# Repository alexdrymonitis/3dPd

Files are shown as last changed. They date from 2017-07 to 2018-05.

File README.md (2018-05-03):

# 3dPd

This repository hosts the code, schematics, and circuit board designs made in Kicad, for a hardware digital modular synthesizer. The audio is programmed in Pure Data and the hardware control in the Arduino language.
This synthesizer is supposed to run on a Raspberry Pi 3 and a Teensy3.2. You're welcome to use any other hardware you like, but this specific hardware is supported and explained here.

## Note about the Arduino code

Go to the Arduino_code directory and read the README.txt file first. That should give you enough information about the Arduino code. Do that before you start reading the Pd patches.

## Note about the Pd patches

The heart of this project is the modular_synthesizer.pd patch. Open it and you'll see some other abstractions in there. Go into the [pd modules] sub-patch and look inside.
Each module must have its own abstraction. There are some tutorial module abstractions which show you how to build your own. Open them and read them carefully.

There's also a debug.pd patch which helps with debugging by showing input from the Teensy and printing various message concerning module connections and LED states.

### Dependencies

This project uses the following external libraries:  
zexy  
comport  
iemmatrix  
iemguts  
ggee  
list-abs  
tabreceive_mult~  

The first five libraries are being installed with "apt-get" and the last two are installed through Deken (In Pd got to Help -> Find externals and type these two names -one at a time-, the highlighted version(s) is good for your system).

Pd-0.47.0 or higher is required.

## General note

I'll upload a wiki with instructions for creating the hardware of a module and the whole system. It's in my TODO list, which will hopefully happen in the near future.
You can watch a demo video of the synthesizer here https://www.youtube.com/watch?v=HD13bDPyBWA

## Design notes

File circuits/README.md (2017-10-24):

# Circuit designs, schematics, and gerber files directory

This README file provides only very basic information about the circuits. I'm planning on releasing a wiki on how to build hardware modules in the next few days.

## Generic note about this directory

In this directory you'll find all the circuits used in this modular synthesizer. It's six circuits in total, each in its own directory. They have been designed in Kicad and all the necessary files are here. Each directory includes a README file which states which extra built-in libraries have been used. The ones I have made especially for these circuits are not mentioned in the README since their directories (library/ and .pretty/) are included here. The directories also include the gerber files for sending them to a manufacturer, plus a .png file for each side (in case of double-sided boards) in case you want to DIY etch it, and a .pdf with the schematic.

If you've never used Kicad before and want to modify any of the circuits, I recommend to read some of the tutorials provided from Kicad's website. This tutorial was very useful for me http://kicad-pcb.org/help/documentation/#_getting_started. If you just want to have them manufactured, you can send the gerber files straight to a manufacturer.

## Note about the circuits

### Parts

There's a parts list in every circuit directory with all the parts of that circuit. Where I thought it was necessary, I provide a link to the datasheet of that part. Parts are identified by their annotation from the schematic. Consult the board design (Pcbnew) to make sure which part goes where.

### Orientation of parts

The orientation of the ICs on the "module_generic_top_board" is not defined by the shape of the footprint part but by the pin numbering. If you're not sure, open Pcbnew, go to View -> 3D Viewer and there you can see the notches of the ICs which indicate their orientation.
The orientation of the IDC connectors can be defined by the pin numbering. On an actual IDC connector, you can see a small arrow at the left side of the notch. This arrow indicates that the left-most pin on the side of the notch, is pin number 1.

### Concerning manufacturing

The boards "module_generic_top_board" and "module_generic_bottom_board" are needed for every module. I would suggest to order these from a manufacturer instead of etching them your self many times. The "module_specific_board" and "module_specific_board"2 are just examples of how you can connect your parts to the generic boards (this will be analyzed in the upcoming wiki). There are two of those because I wanted to provide both orientations for the potentiometers, because of the knobs one can find (they are D-shaped knobs, so orientation is rather important). You can order few of these as well, since it is designed in such a way that can host many different layouts.

The "power_bus", "power_distributor", and "teensy_motherboard" are designed as single-side circuit boards (with the "teensy_motherboard" using three jumpers, the "power_bus" only one, and the "power_distributor" none) so that it's easier to etch them yourself. You'll need only one per board (unless you want to build more than 16 modules, then you'll need a second "power_bus", explained in the upcoming wiki), so ordering those from a manufacturer might not work out.

Eacn board has a .pdf file which you can print for DIY etching, either with toner transfer or with photo-resistant boards. The "module_generic_top_board", "module_generic_bottom_board", and "module_specific_board" have two .pdf, one for each side, while the rest three have only one .pdf file.

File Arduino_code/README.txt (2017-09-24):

Before uploading code to the Teensy you must make a small test. I had problems sending the value 13 from the Teensy to Pd. Arduino's Serial.write() function didn't work, and instead of 13 I was receiving a 10.
Searching I found that Serial.print((char)13) might do the job. On my laptop with an Arduino Uno, this does work indeed (while Serial.write(13) doesn't even work on my laptop), but on my Raspberry Pi even this didn't work, and again I was receiving a 10 in Pd.
I don't know why this is happening. I sent a mail to Pd's mailing list, but Matrin Peach, the developer of [comport] reported that he can print 13 with Serial.write() without any issues and that [comport] doesn't interpret anything. It can be because of 13 being ASCII carriage return and 10 being the line feed, which in some cases (like Arduino's Serial.println() funciton) these two ASCII values are combined. It can possibly be an Arduino compiler problem, I don't know.
I found a work around this problem by adding some extra data to the data sent from the Teensy to Pd. You should do the following test:

Upload the write.ino Arduino sketch to the Teensy and open the test13.pd patch. If you get 13 printed in Pd's console, you're good to go. Upload the modular_synthesizer.ino sketch and open the modular_synthesizer.pd patch.
If instead of 13 you get 10 printed to Pd's console, open the print13.ino sketch and the test13.pd patch. If you get 13 printed in Pd's console, you're good to go. Upload the modular_synthesizer_print.ino sketch and open the modular_synthesizer.pd patch.
If you still get 10 printed to Pd's console, upload the modular_synthesizer13.ino sketch to the Teensy. In modular_synthesizer.pd patch, change the [arduino_data] abstraction with [arduino_data13]. The rest should work as expected.

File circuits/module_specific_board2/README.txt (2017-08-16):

This board is a rather generic design for mounting potentiometers and wiring banana terminals, switches and LEDs to a module. Each module will have its own layout, so the board that hosts the parts of the module is rather specific than generic. Still, this board can host quite some different layouts the way it is designed.

The digital inputs and outputs are broken out to the right side and bottom side of the board respctively. The inputs start counting from the top and the outputs from left to right.

Four potentiometers are placed on this board which are connected to the first four multiplexer inputs. The other four are broken out on the right side of the top header, where the top pin of the four-pin header is mux pin 8, and the bottom is mux pin 5. I have included 10K pull-down resistors in case you run out of digital inputs but have some space multiplexer pins. In this case you can attach a pull-down resistor to one of these pins (or all four) and use it for a switch.

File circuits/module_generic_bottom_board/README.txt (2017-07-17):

This circuit contains the switches schematic parts library from /usr/share/kicak/library

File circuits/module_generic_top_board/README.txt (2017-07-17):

This circuit contains the Connectors_JST_PH.pretty footprint library in the project specific libraries, from ${KISYSMOD}/Connectors_JST_PH.pretty

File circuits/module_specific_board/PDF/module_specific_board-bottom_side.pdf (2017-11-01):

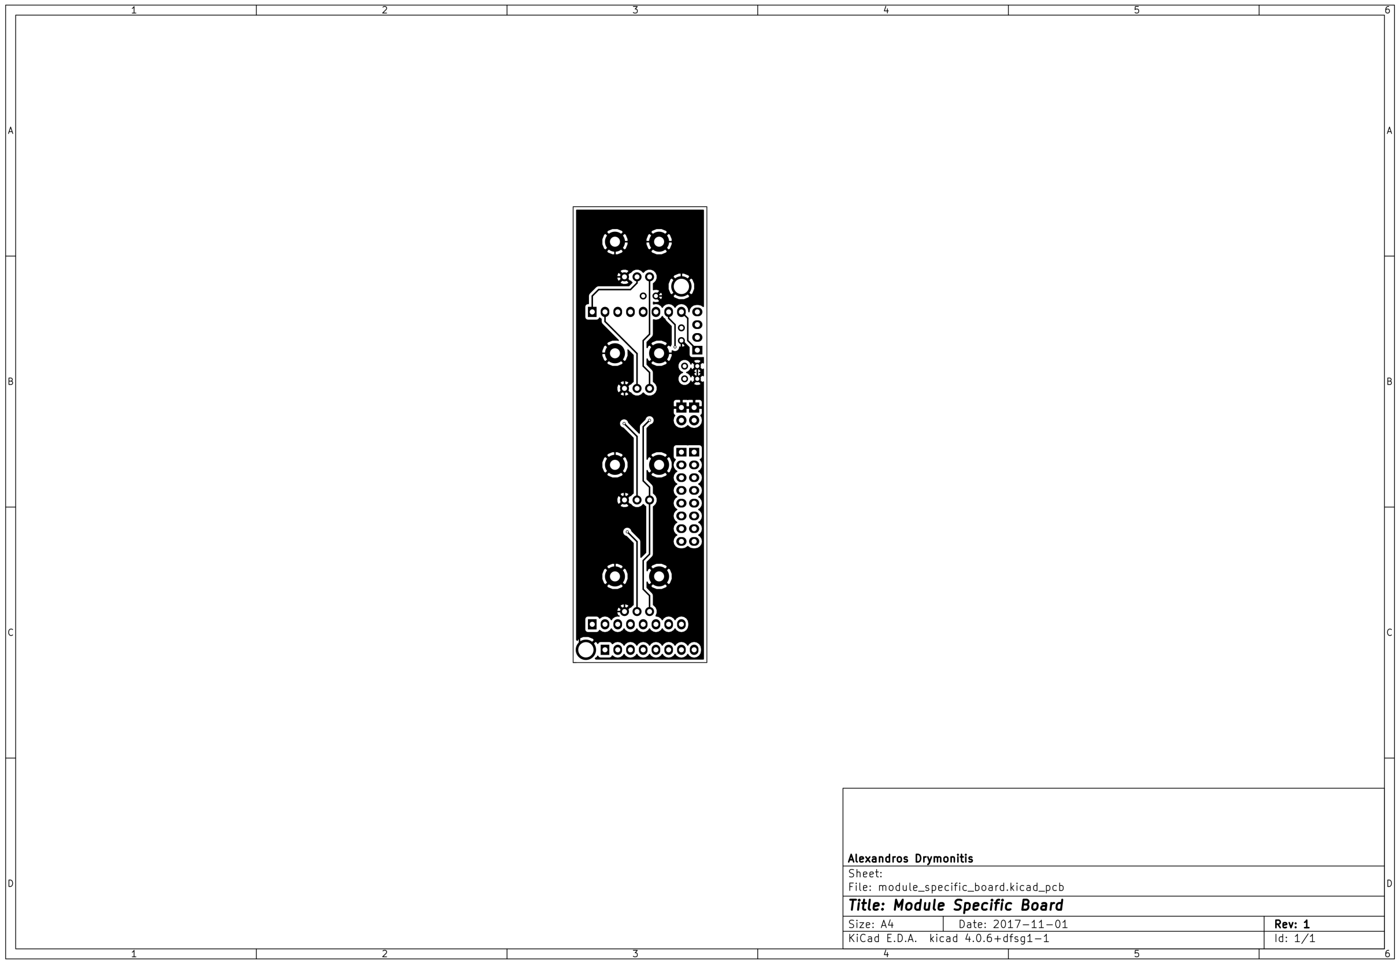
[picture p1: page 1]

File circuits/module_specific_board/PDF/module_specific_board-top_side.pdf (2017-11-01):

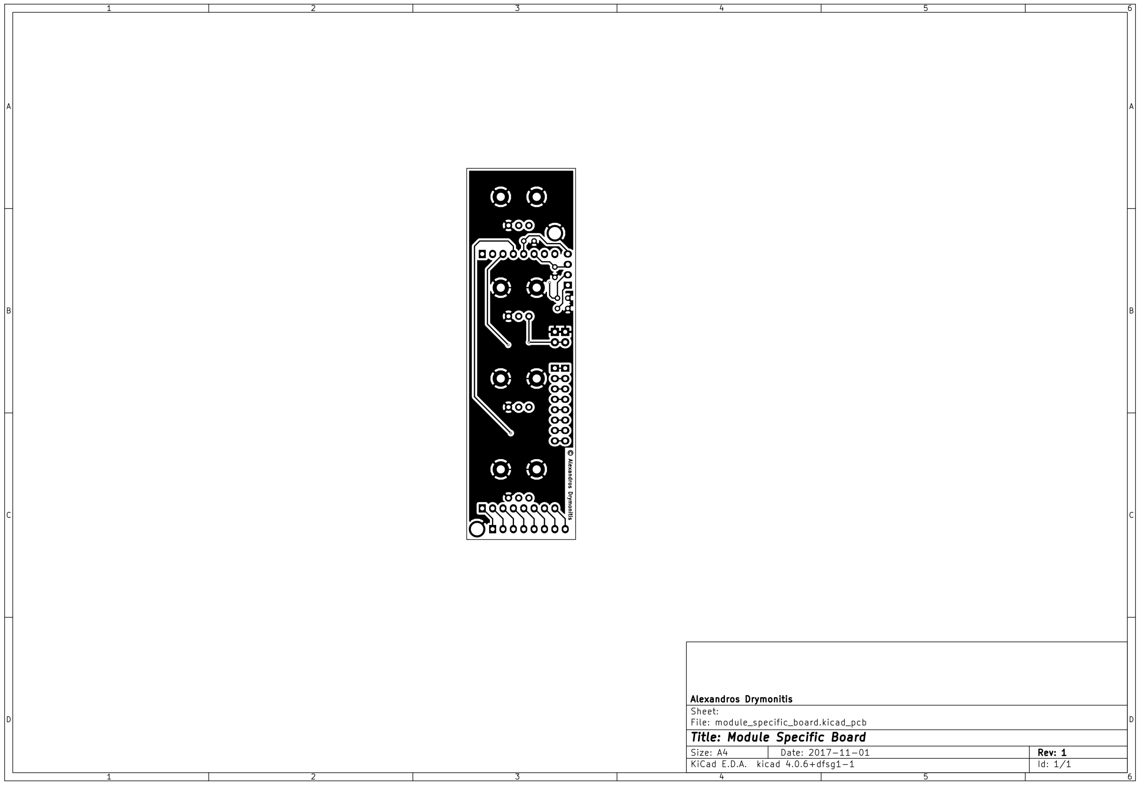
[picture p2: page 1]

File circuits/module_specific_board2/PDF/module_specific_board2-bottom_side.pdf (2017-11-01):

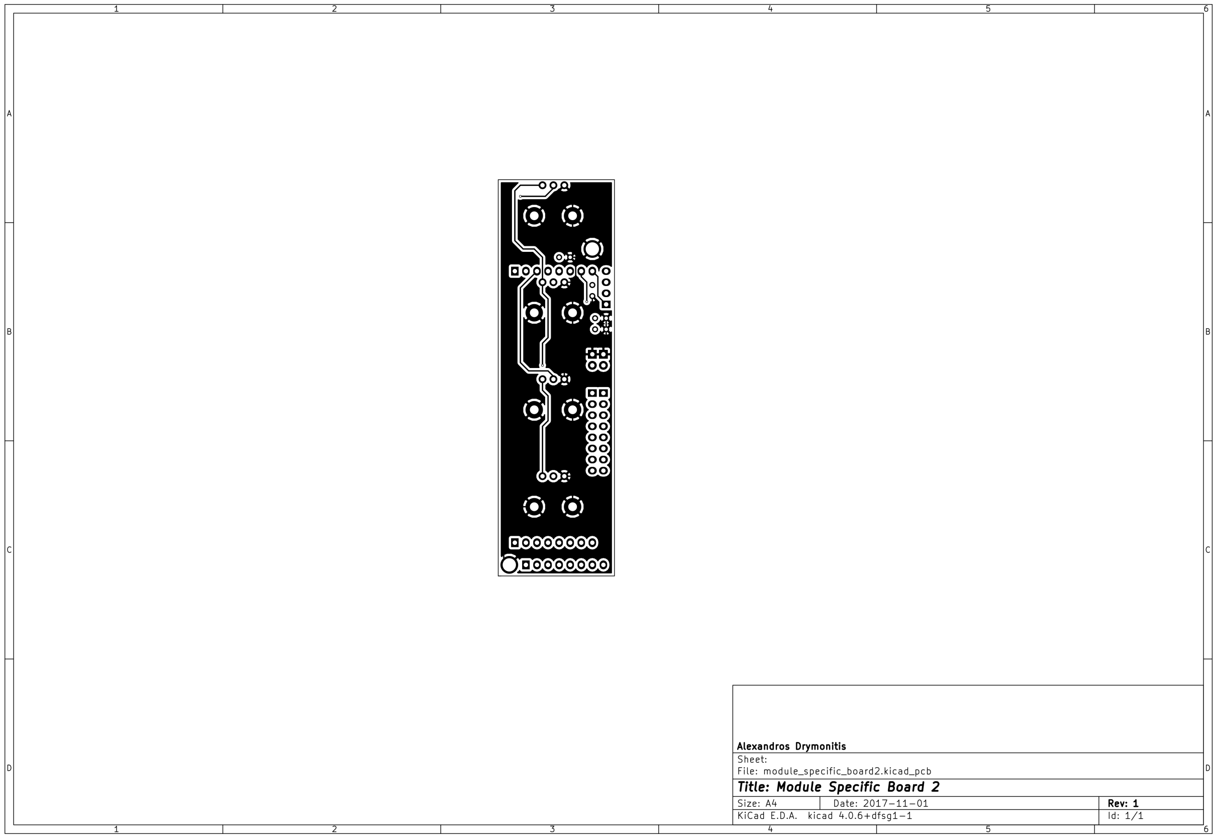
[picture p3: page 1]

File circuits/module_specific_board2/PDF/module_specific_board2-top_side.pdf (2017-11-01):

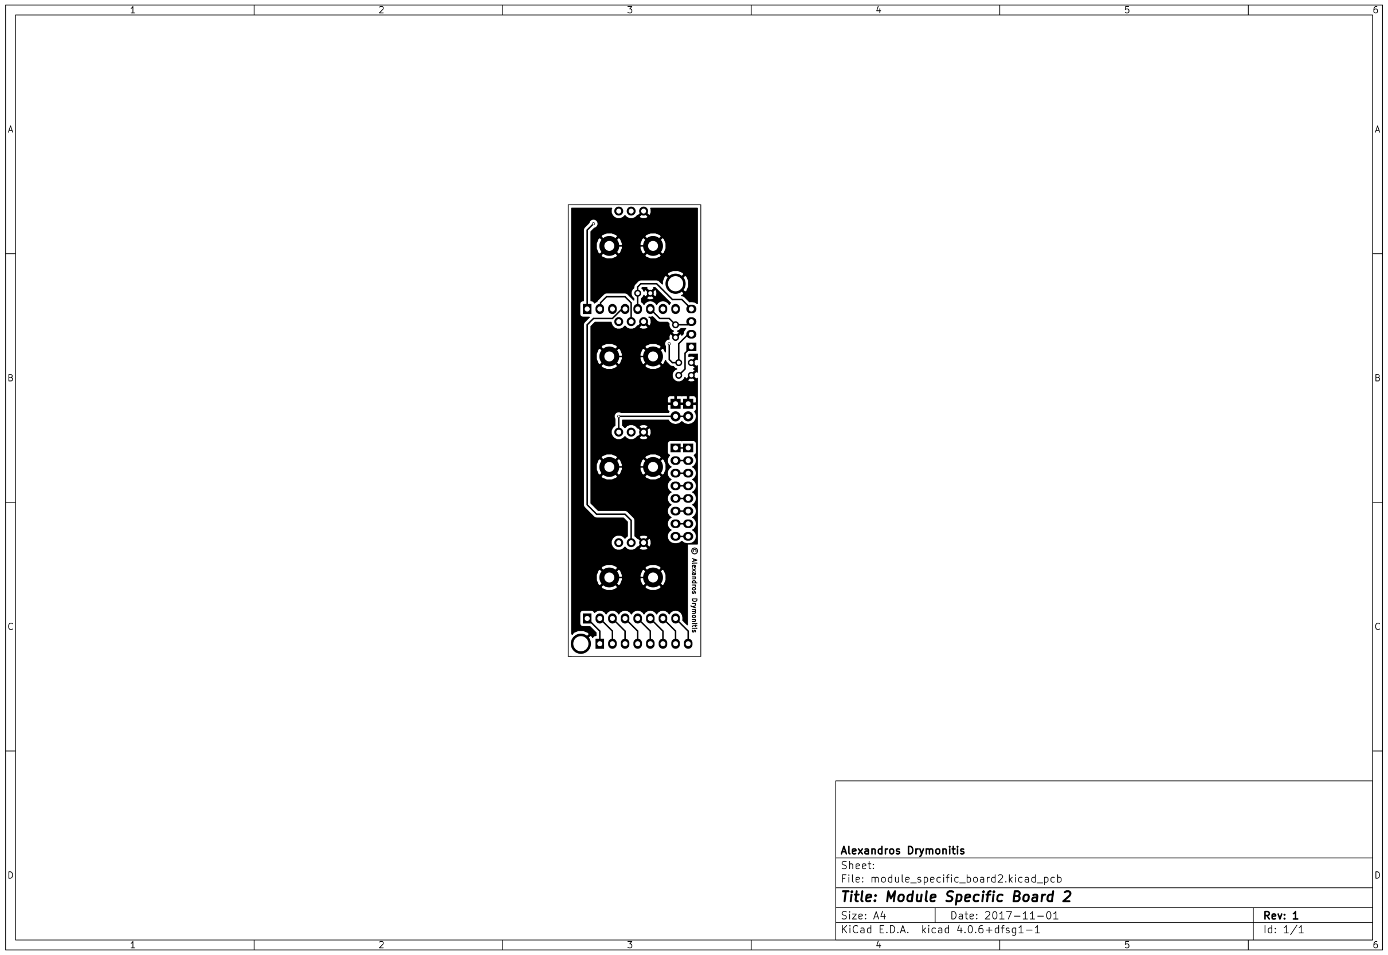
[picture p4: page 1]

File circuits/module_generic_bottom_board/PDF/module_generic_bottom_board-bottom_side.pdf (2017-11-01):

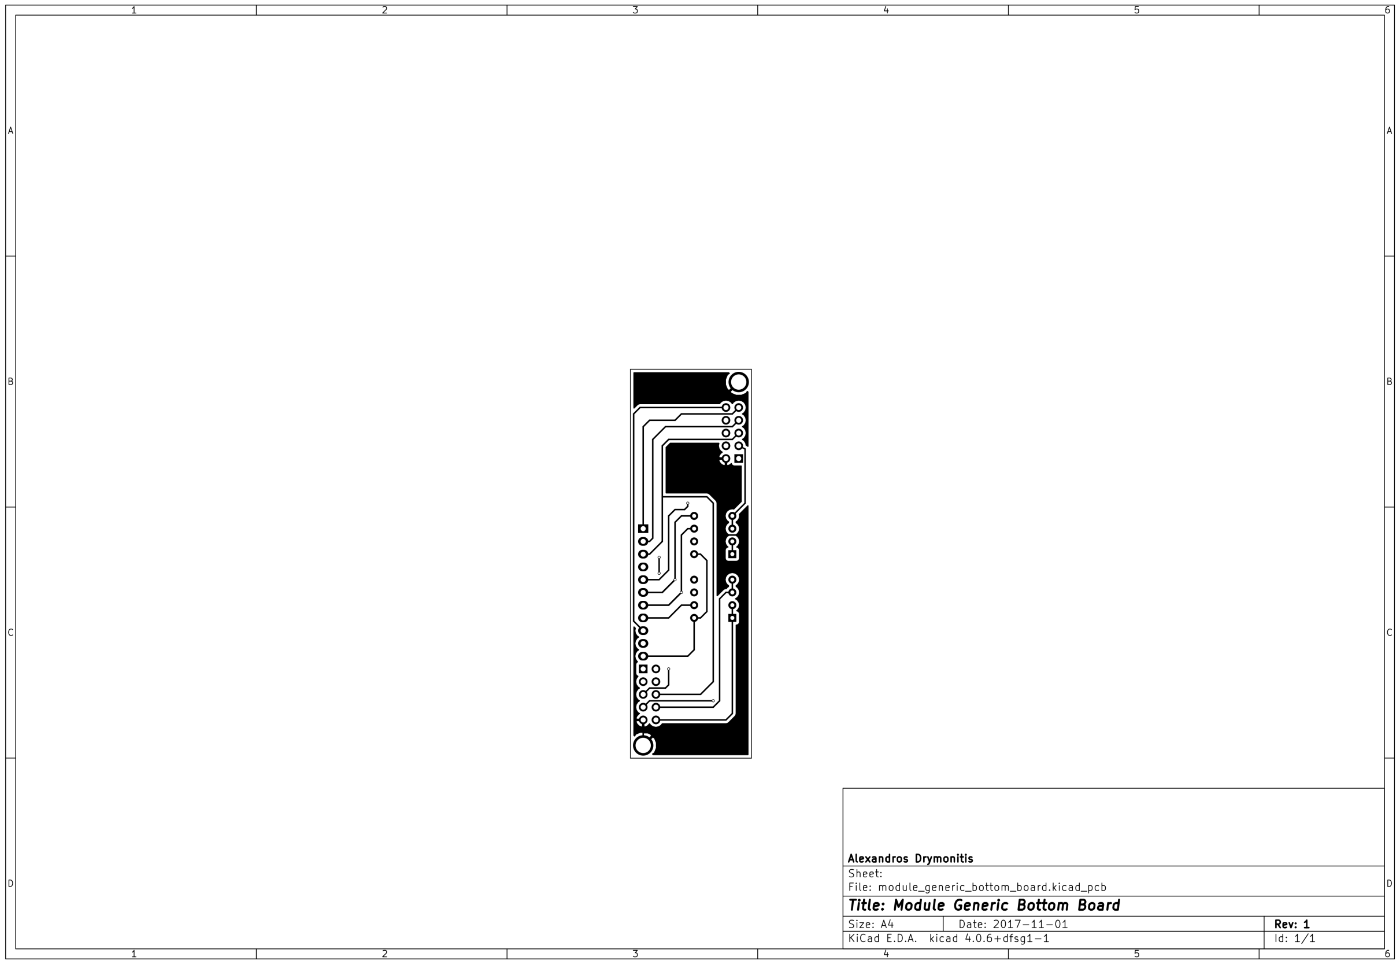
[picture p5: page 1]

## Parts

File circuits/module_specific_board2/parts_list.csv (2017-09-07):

Reference | Value | Footprint | Datasheet
P6 | CONN_01X02 | Header Male Straight 2-pin
P3 | CONN_01X08 | Header Male Straight 8-pin
P4 | CONN_01X08 | Header Male Straight 8-pin
P5 | CONN_01X08 | Header Male Straight 8-pin
J1 | Pot | ALPS Rotary Potentiometer RK09L114001T | http://www.alps.com/prod/info/E/HTML/Potentiometer/RotaryPotentiometers/RK09L/RK09L1140A66.html
J2 | Pot | ALPS Rotary Potentiometer RK09L114001T | http://www.alps.com/prod/info/E/HTML/Potentiometer/RotaryPotentiometers/RK09L/RK09L1140A66.html
J3 | Pot | ALPS Rotary Potentiometer RK09L114001T | http://www.alps.com/prod/info/E/HTML/Potentiometer/RotaryPotentiometers/RK09L/RK09L1140A66.html
J4 | Pot | ALPS Rotary Potentiometer RK09L114001T | http://www.alps.com/prod/info/E/HTML/Potentiometer/RotaryPotentiometers/RK09L/RK09L1140A66.html
R1 | 10K resistor, 1/4W | Discret:R1
R2 | 10K resistor, 1/4W | Discret:R1
R3 | 10K resistor, 1/4W | Discret:R1
R4 | 10K resistor, 1/4W | Discret:R1

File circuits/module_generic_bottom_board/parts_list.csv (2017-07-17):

Reference | Value | Type
P2 | CONN_02X05 | IDC Connector 2x5 Angled
P1 | CONN_02X05 | IDC Connector 2x5 Angled
P3 | CONN_01X11 | Header Male 11-pin Straight
S1 | SW_DIP_x4 | DIP Switch 4-position Piano Type
S2 | SW_DIP_x4 | DIP Switch 4-position Piano Type

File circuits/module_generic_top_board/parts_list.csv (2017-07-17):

Reference | Value | Type | Datasheet
C1 | 0.1uF | Capacitor Ceramic Unpolarized
C2 | 0.1uF | Capacitor Ceramic Unpolarized
C3 | 0.1uF | Capacitor Ceramic Unpolarized
RR1 | 10K | Resistor Network 8 + 1
P2 | CONN_01X08 | Female Header Straight 8-pin 0.1 Inch
P1 | CONN_01X08 | Female Header Straight 8-pin 0.1 Inch
P4 | CONN_01X08 | Female Header Straight 8-pin 0.1 Inch
P5 | CONN_01X02 | Female Header Straight 2-pin 0.1 Inch
P6 | CONN_01X11 | Female Header Straight 11-pin 0.1 Inch
P3 | CONN_01X03 | JST PH Connector Male Angled 3-pin
U3 | 74HC165 | 8-bit Input Shift Register | https://cdn.sparkfun.com/datasheets/BreakoutBoards/sn54hc165.pdf
U2 | 74HC595 | 8-bit Output Shift Register | http://www.ti.com/lit/ds/symlink/sn74hc595.pdf
U1 | 4051 | 8-channel Analog Multiplexer | http://grobotronics.com/images/datasheets/schs354a.pdf
R1 | 10K | Resistor

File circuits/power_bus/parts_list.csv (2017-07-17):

Reference | Value | Type | Datasheet
U1 | CD4067 | 16-channel Analog Multiplexer 4067 | https://www.sparkfun.com/datasheets/IC/CD74HC4067.pdf
P2 | CONN_01X03 | JST PH Connector Male Angled 3-pin
P10 | CONN_01X03 | JST PH Connector Male Angled 3-pin
P14 | CONN_01X03 | JST PH Connector Male Angled 3-pin
P19 | CONN_01X03 | JST PH Connector Male Angled 3-pin
P3 | CONN_01X03 | JST PH Connector Male Angled 3-pin
P11 | CONN_01X03 | JST PH Connector Male Angled 3-pin
P15 | CONN_01X03 | JST PH Connector Male Angled 3-pin
P20 | CONN_01X03 | JST PH Connector Male Angled 3-pin
P4 | CONN_01X03 | JST PH Connector Male Angled 3-pin
P12 | CONN_01X03 | JST PH Connector Male Angled 3-pin
P16 | CONN_01X03 | JST PH Connector Male Angled 3-pin
P21 | CONN_01X03 | JST PH Connector Male Angled 3-pin
P5 | CONN_01X03 | JST PH Connector Male Angled 3-pin
P13 | CONN_01X03 | JST PH Connector Male Angled 3-pin
P17 | CONN_01X03 | JST PH Connector Male Angled 3-pin
P22 | CONN_01X03 | JST PH Connector Male Angled 3-pin
P1 | CONN_02X03 | IDC Connector Male 2x3 Straight
C2 | 0.1uF | Capacitor Ceramic Unpolarized
P18 | CONN_01X02 | Screw Terminal 2-pin 5mm Pitch
R1 | 10K | Resistor

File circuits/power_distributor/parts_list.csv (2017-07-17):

Reference | Value | Footprint | Datasheet
P1 | CONN_01X02 | Screw Temrinal 2-pin 5mm Pitch
P2 | CONN_01X02 | Screw Temrinal 2-pin 5mm Pitch
P3 | CONN_01X02 | Screw Temrinal 2-pin 5mm Pitch
P4 | CONN_01X02 | Screw Temrinal 2-pin 5mm Pitch
P5 | CONN_01X02 | Screw Temrinal 2-pin 5mm Pitch
U1 | LD1117S33TR | Voltage Regulator LD1117 - 3.3V 800mA | http://grobotronics.com/images/datasheets/ld1117.pdf
C1 | 100nF | Capacitor Ceramic Unpolarized
C2 | 10uF | Capacitor Electrolytic Polarized

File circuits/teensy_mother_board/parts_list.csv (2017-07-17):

Reference | Value | Footprint
P9 | CONN_01X14 | Header Male 14-pin Straight (to host Teensy)
P8 | CONN_01X14 | Header Male 14-pin Straight (to host Teensy)
P5 | CONN_02X05 | IDC Connector Male 2x5 Straight
P6 | CONN_02X03 | IDC Connector Male 2x3 Straight
P7 | CONN_02X03 | IDC Connector Male 2x3 Straight
P10 | CONN_01X02 | Screw Terminal 2-pin 5mm Pitch
P11 | CONN_01X02 | JST PH Connector Male Angled 2-pin
P13 | CONN_01X02 | JST PH Connector Male Angled 2-pin
P12 | CONN_01X02 | JST PH Connector Male Angled 2-pin

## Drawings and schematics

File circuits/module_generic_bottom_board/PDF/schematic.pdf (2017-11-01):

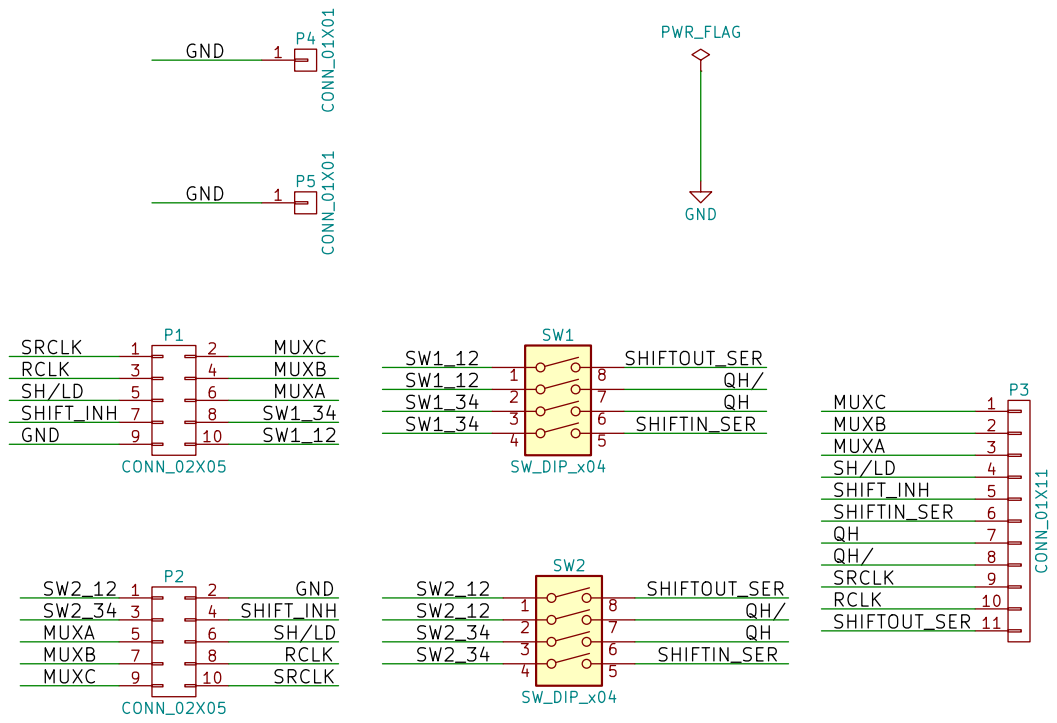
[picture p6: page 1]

File: module_generic_bottom_board.sch Sheet: / Alexandros Drymonitis

Id: 1/1 Title: ModuleGeneric Bottom Board

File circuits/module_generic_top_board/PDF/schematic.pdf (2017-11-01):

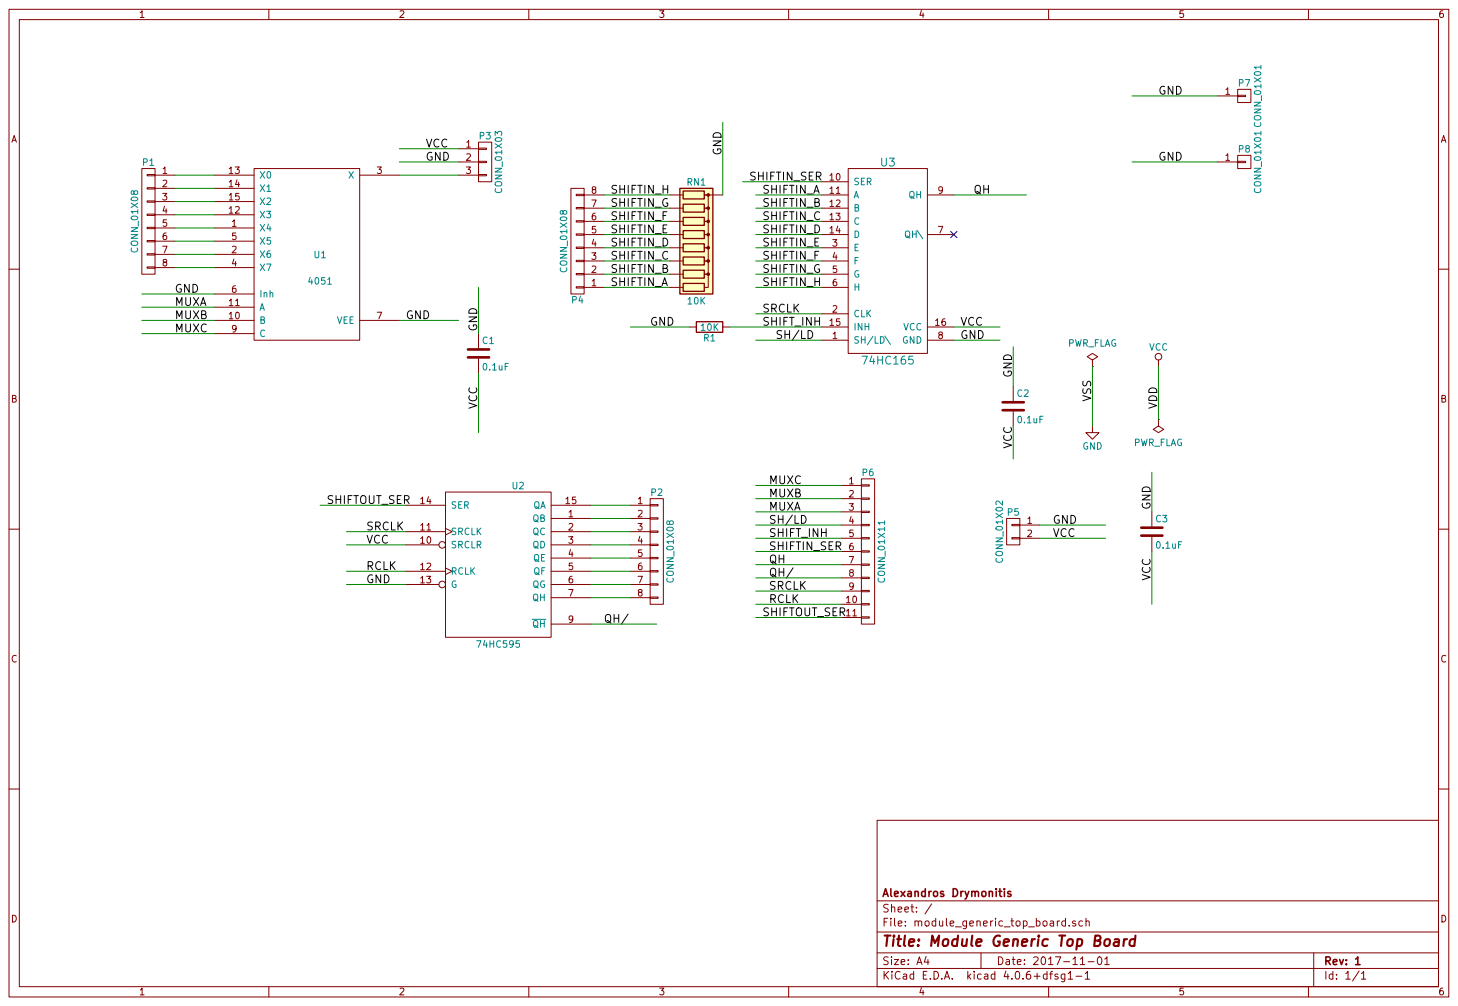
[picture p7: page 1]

GND MUXA MUXB MUXC

File: module_generic_top_board.sch Sheet: / Alexandros Drymonitis

Id: 1/1 Title: Module Generic Top Board

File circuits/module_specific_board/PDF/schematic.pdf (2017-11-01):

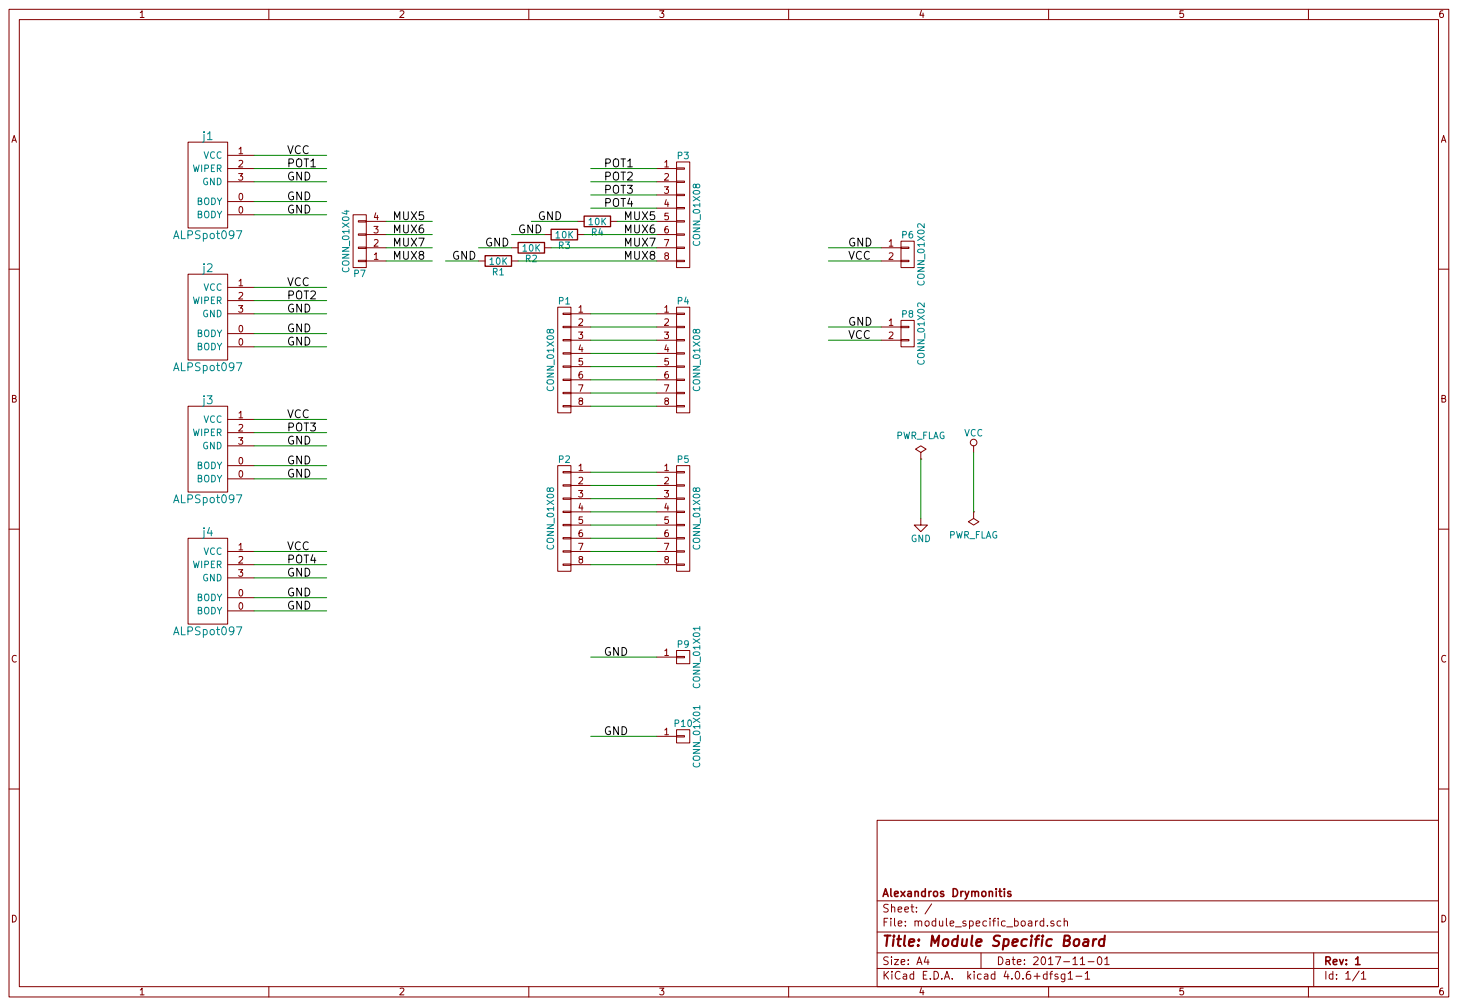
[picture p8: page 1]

Id: 1/1 Title: Module Specific Board

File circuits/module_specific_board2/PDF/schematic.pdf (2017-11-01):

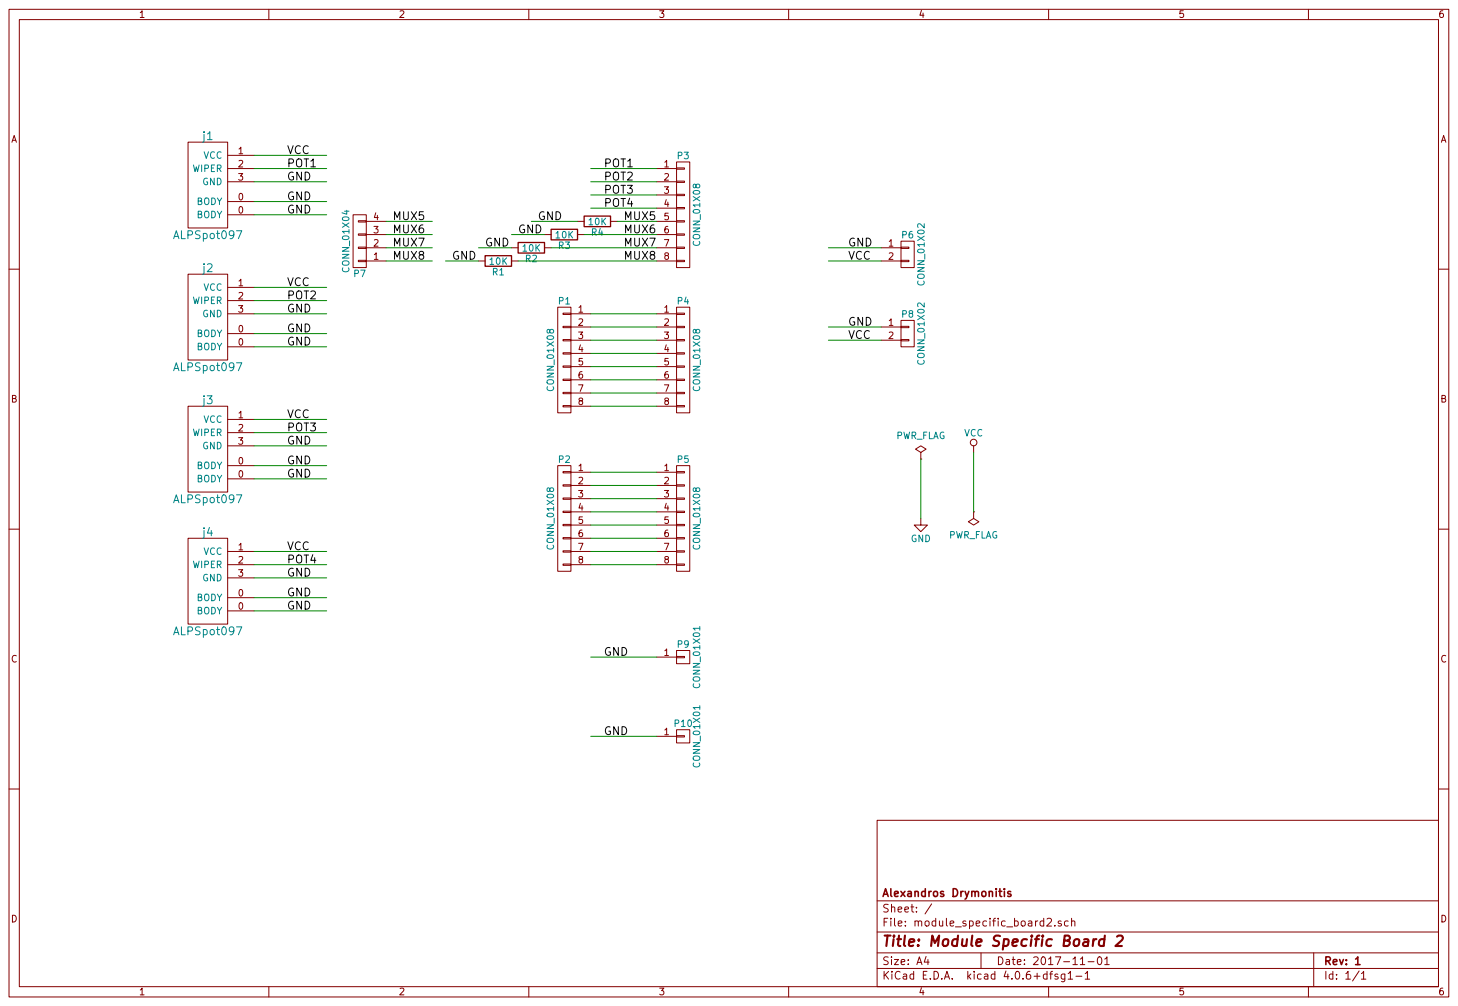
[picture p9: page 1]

Id: 1/1 Title: Module Specific Board 2

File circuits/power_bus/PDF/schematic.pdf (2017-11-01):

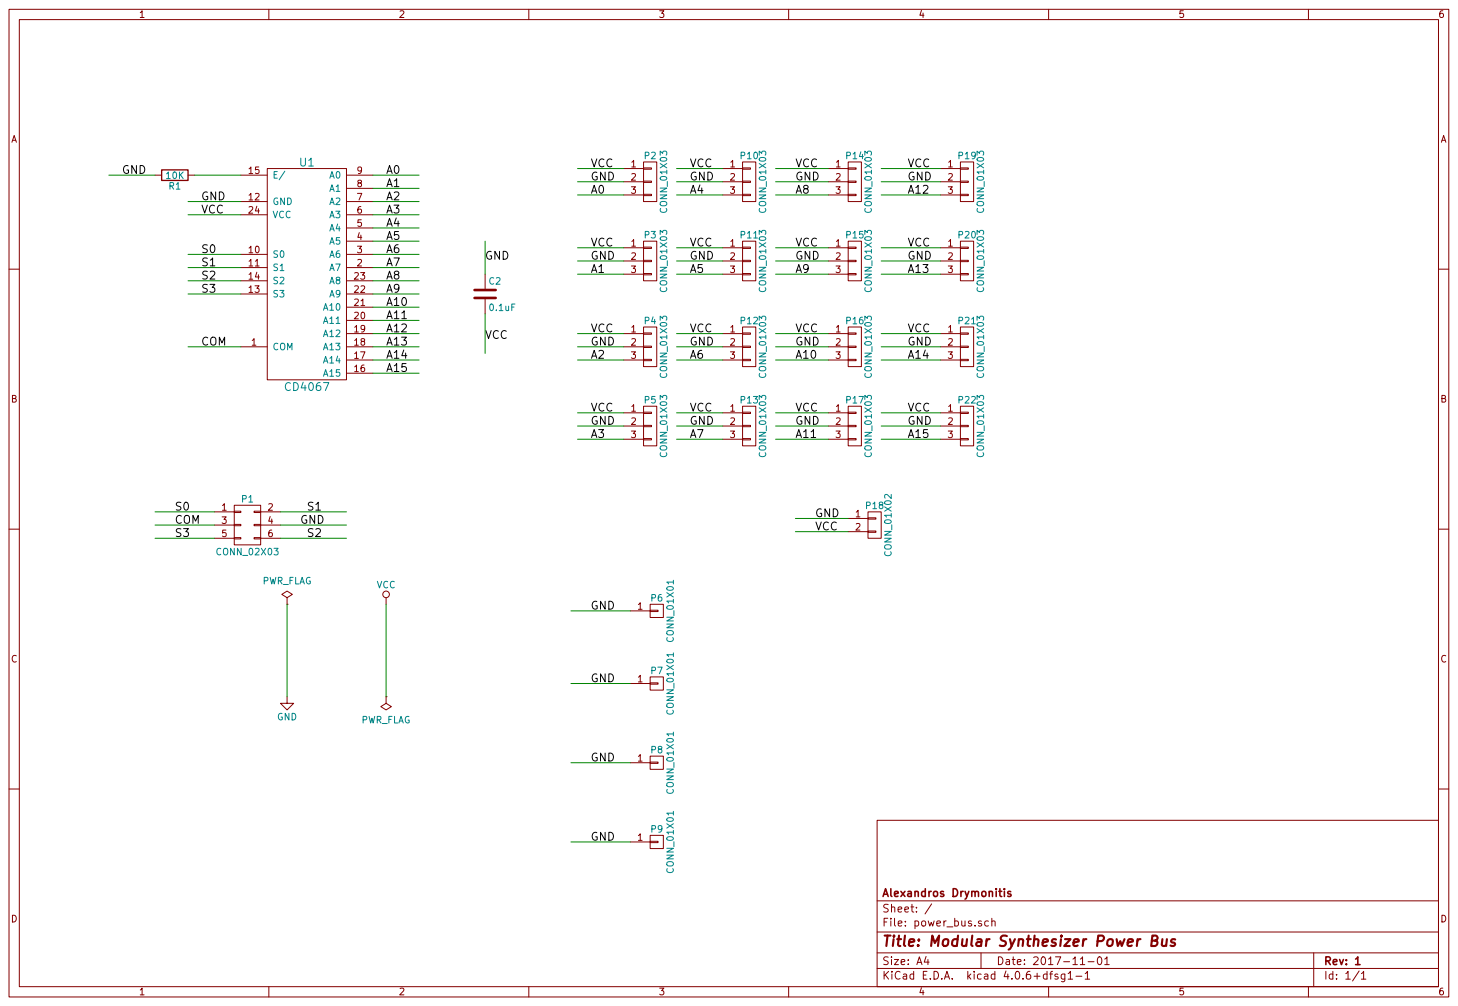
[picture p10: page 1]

File: power_bus.sch Sheet: / Alexandros Drymonitis

Id: 1/1 Title: Modular Synthesizer Power Bus

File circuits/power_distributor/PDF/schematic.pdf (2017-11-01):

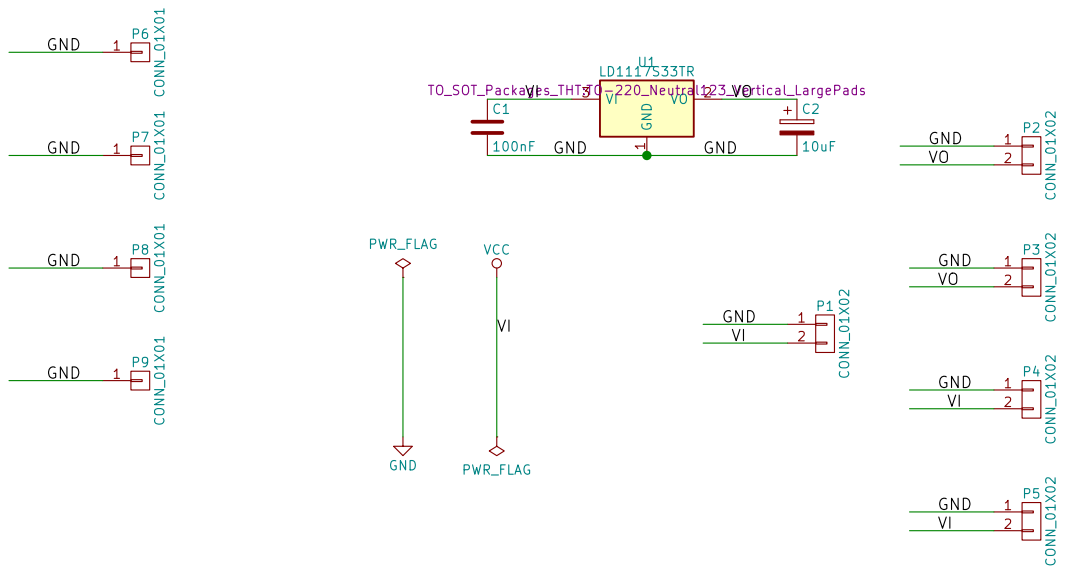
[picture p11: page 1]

File: power_distributor.sch Sheet: / Alexandros Drymonitis

Id: 1/1 Title: Modular Synthesizer Power Distributor

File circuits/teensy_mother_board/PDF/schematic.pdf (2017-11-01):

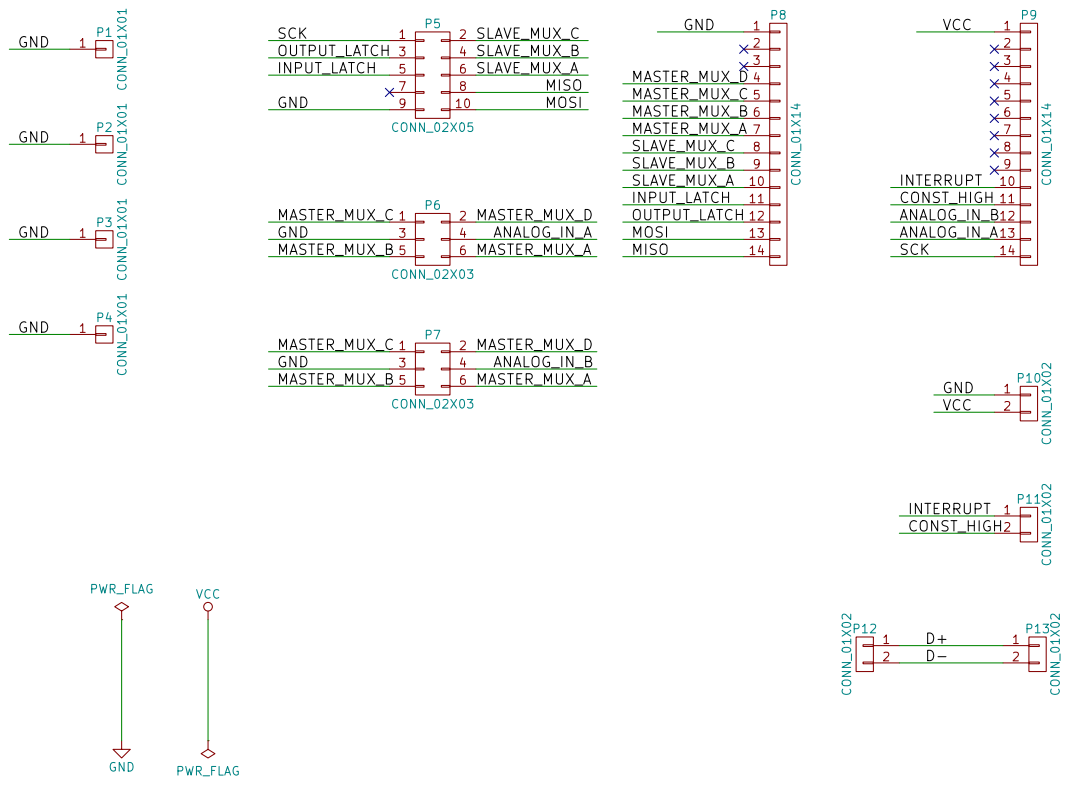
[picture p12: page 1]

File: teensy_mother_board.sch Sheet: / Alexandros Drymonitis

Id: 1/1 Title: Teensy Mother Board

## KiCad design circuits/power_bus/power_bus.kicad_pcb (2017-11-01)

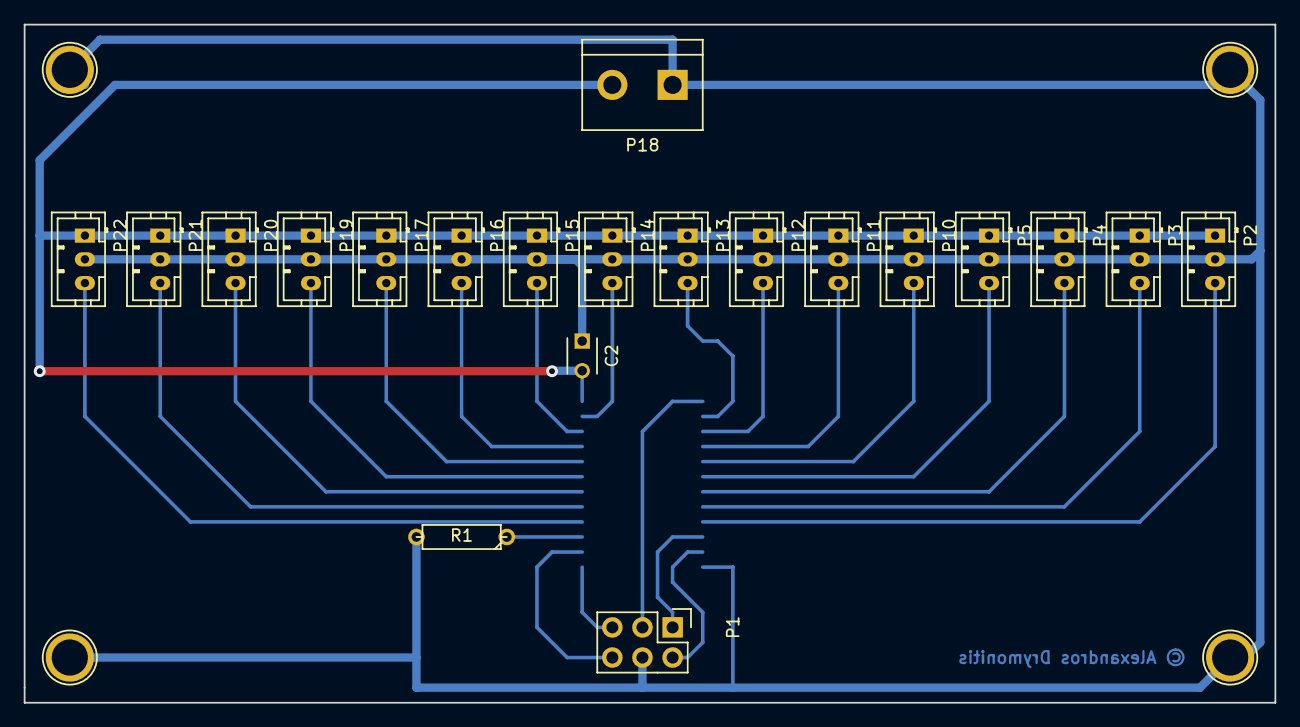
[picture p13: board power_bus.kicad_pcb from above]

Board: 2 copper layers, 105.4 x 57.2 mm, 25 parts (1 on the bottom side), 24 nets.

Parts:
C2: 0.1uF; C_Disc_D3_P2.5
P1: CONN_02X03; Pin_Header_Straight_2x03
P2, P3, P4, P5, P10, P11, P12, P13, P14, P15, P16, P17, P19, P20, P21, P22: CONN_01X03; Connectors_JST_B3B-PH-K
P6, P7, P8, P9: CONN_01X01; hole
P18: CONN_01X02; bornier2
R1: 10K; R3
U1: CD4067

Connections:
/A0: P2.3, U1.9
/A1: P3.3, U1.8
/A2: P4.3, U1.7
/A3: P5.3, U1.6
/A4: P10.3, U1.5
/A5: P11.3, U1.4
/A6: P12.3, U1.3
/A7: P13.3, U1.2
/A8: P14.3, U1.23
/A9: P15.3, U1.22
/A10: P16.3, U1.21
/A11: P17.3, U1.20
/A12: P19.3, U1.19
/A13: P20.3, U1.18
/A14: P21.3, U1.17
/A15: P22.3, U1.16
/COM: P1.3, U1.1
/S0: P1.1, U1.10
/S1: P1.2, U1.11
/S2: P1.6, U1.14
/S3: P1.5, U1.13
GND: C2.1, P1.4, P2.2, P3.2, P4.2, P5.2, P6.1, P7.1, P8.1, P9.1, P10.2, P11.2, P12.2, P13.2, P14.2, P15.2, P16.2, P17.2, P18.1, P19.2, P20.2, P21.2, P22.2, R1.2, U1.12
unnamed: R1.1, U1.15
VCC: C2.2, P2.1, P3.1, P4.1, P5.1, P10.1, P11.1, P12.1, P13.1, P14.1, P15.1, P16.1, P17.1, P18.2, P19.1, P20.1, P21.1, P22.1, U1.24

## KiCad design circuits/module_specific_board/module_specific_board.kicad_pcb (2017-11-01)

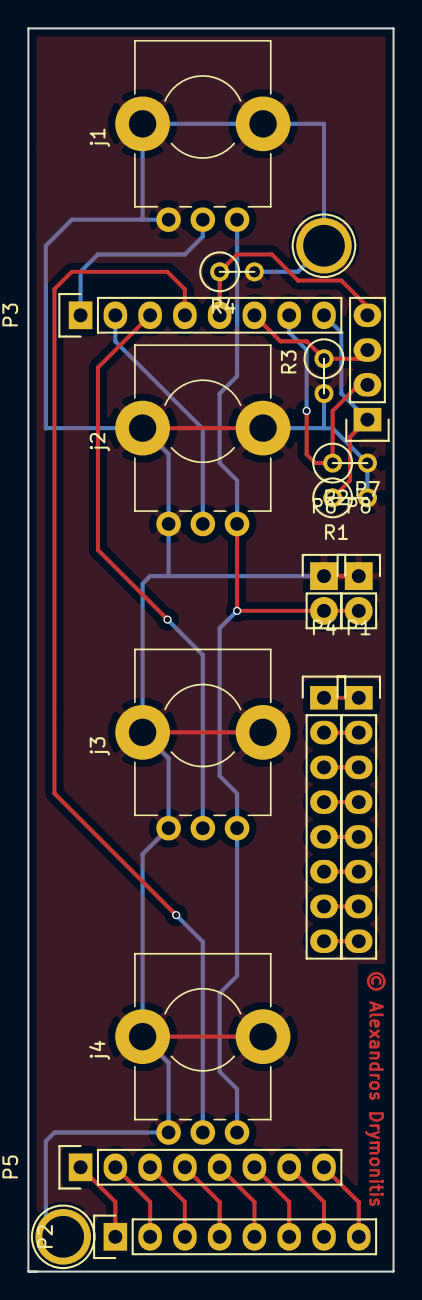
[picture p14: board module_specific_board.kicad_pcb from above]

Board: 2 copper layers, 26.7 x 90.8 mm, 18 parts (0 on the bottom side), 26 nets.

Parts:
P1, P2, P3, P4, P5: CONN_01X08; Pin_Header_Straight_1x08
P6, P8: CONN_01X02; Pin_Header_Straight_1x02
P7: CONN_01X04; Pin_Header_Straight_1x04
P9, P10: CONN_01X01; hole
R1, R2, R3, R4: 10K; R1
j1, j2, j3, j4: ALPSpot097; Potentiometer_Alps_RK09K_Horizontal

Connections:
/MUX5: P3.5, P7.4, R4.1
/MUX6: P3.6, P7.3, R3.1
/MUX7: P3.7, P7.2, R2.1
/MUX8: P3.8, P7.1, R1.1
/POT1: P3.1, j1.2
/POT2: P3.2, j2.2
/POT3: P3.3, j3.2
/POT4: P3.4, j4.2
GND: P6.1, P8.1, P9.1, P10.1, R1.2, R2.2, R3.2, R4.2, j1.0, j1.3, j2.0, j2.3, j3.0, j3.3, j4.0, j4.3
unnamed: P1.1, P4.1
unnamed: P1.2, P4.2
unnamed: P1.3, P4.3
unnamed: P1.4, P4.4
unnamed: P1.5, P4.5
unnamed: P1.6, P4.6
unnamed: P1.7, P4.7
unnamed: P1.8, P4.8
unnamed: P2.1, P5.1
unnamed: P2.2, P5.2
unnamed: P2.3, P5.3
unnamed: P2.4, P5.4
unnamed: P2.5, P5.5
unnamed: P2.6, P5.6
unnamed: P2.7, P5.7
unnamed: P2.8, P5.8
VCC: P6.2, P8.2, j1.1, j2.1, j3.1, j4.1

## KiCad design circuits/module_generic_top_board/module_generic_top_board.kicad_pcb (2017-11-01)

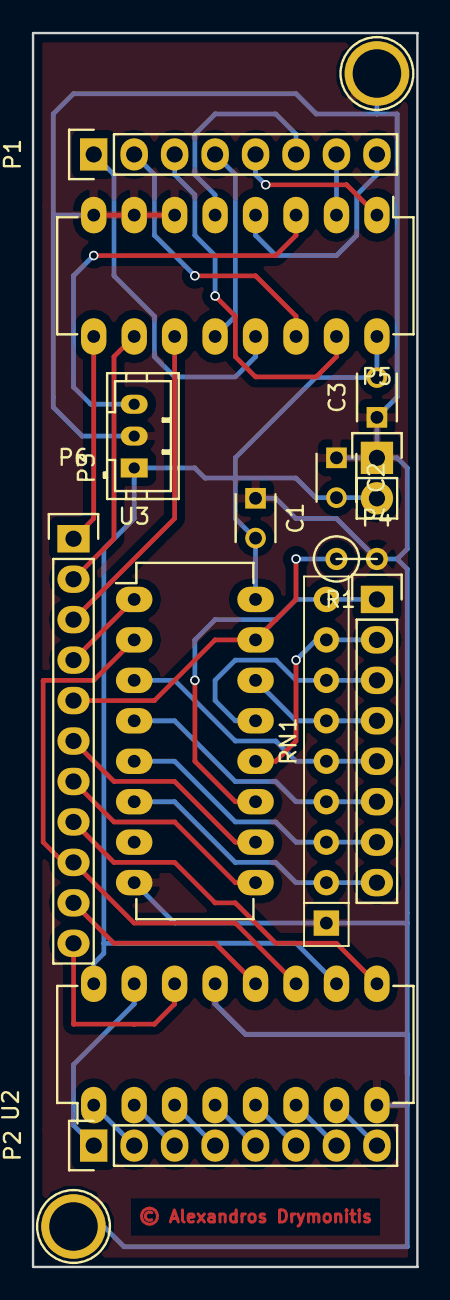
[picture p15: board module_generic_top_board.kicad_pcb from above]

Board: 2 copper layers, 24.1 x 77.5 mm, 16 parts (0 on the bottom side), 38 nets.

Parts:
C1, C2, C3: 0.1uF; C_Disc_D3_P2.5
P1, P2, P4: CONN_01X08; Pin_Header_Straight_1x08
P3: CONN_01X03; Connectors_JST_B3B-PH-K
P5: CONN_01X02; Pin_Header_Straight_1x02
P6: CONN_01X11; Pin_Header_Straight_1x11
P7, P8: CONN_01X01; hole
R1: 10K; R1
RN1: 10K; R_Array_SIP9
U1: 4051; DIP-16_W7.62mm_LongPads
U2: 74HC595; DIP-16_W7.62mm_LongPads
U3: 74HC165; DIP-16_W7.62mm_LongPads

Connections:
/MUXA: P6.3, U1.11
/MUXB: P6.2, U1.10
/MUXC: P6.1, U1.9
/QH: P6.7, U3.9
/QH/: P6.8, U2.9
/RCLK: P6.10, U2.12
/SH/LD: P6.4, U3.1
/SHIFTIN_A: P4.1, RN1.9, U3.11
/SHIFTIN_B: P4.2, RN1.8, U3.12
/SHIFTIN_C: P4.3, RN1.7, U3.13
/SHIFTIN_D: P4.4, RN1.6, U3.14
/SHIFTIN_E: P4.5, RN1.5, U3.3
/SHIFTIN_F: P4.6, RN1.4, U3.4
/SHIFTIN_G: P4.7, RN1.3, U3.5
/SHIFTIN_H: P4.8, RN1.2, U3.6
/SHIFTIN_SER: P6.6, U3.10
/SHIFTOUT_SER: P6.11, U2.14
/SHIFT_INH: P6.5, R1.1, U3.15
/SRCLK: P6.9, U2.11, U3.2
GND: C1.1, C2.1, C3.1, P3.2, P5.1, P7.1, P8.1, R1.2, RN1.1, U1.6, U1.7, U1.8, U2.8, U2.13, U3.8
unnamed: P1.1, U1.13
unnamed: P1.2, U1.14
unnamed: P1.3, U1.15
unnamed: P1.4, U1.12
unnamed: P1.5, U1.1
unnamed: P1.6, U1.5
unnamed: P1.7, U1.2
unnamed: P1.8, U1.4
unnamed: P2.1, U2.15
unnamed: P2.2, U2.1
unnamed: P2.3, U2.2
unnamed: P2.4, U2.3
unnamed: P2.5, U2.4
unnamed: P2.6, U2.5
unnamed: P2.7, U2.6
unnamed: P2.8, U2.7
unnamed: P3.3, U1.3
VCC: C1.2, C2.2, C3.2, P3.1, P5.2, U1.16, U2.10, U2.16, U3.16

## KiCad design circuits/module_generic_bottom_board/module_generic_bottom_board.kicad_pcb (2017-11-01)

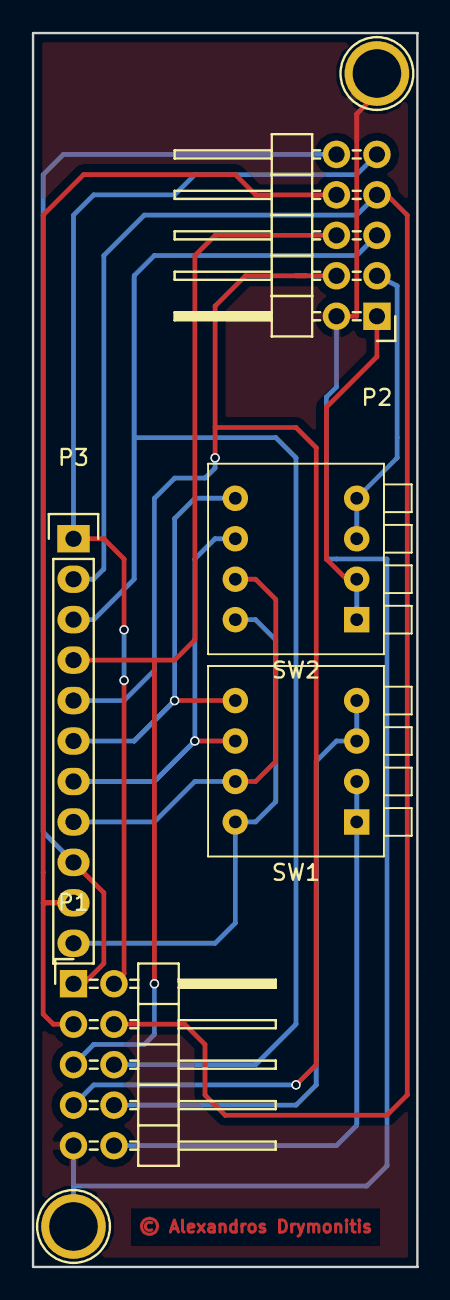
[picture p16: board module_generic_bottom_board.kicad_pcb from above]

Board: 2 copper layers, 24.1 x 77.5 mm, 7 parts (0 on the bottom side), 16 nets.

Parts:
P1, P2: CONN_02X05; Pin_Header_Angled_2x05
P3: CONN_01X11; Pin_Header_Straight_1x11
P4, P5: CONN_01X01; hole
SW1, SW2: SW_DIP_x04; SW_DIP_x4_W7.62mm_Piano

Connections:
/MUXA: P1.6, P2.5, P3.3
/MUXB: P1.4, P2.7, P3.2
/MUXC: P1.2, P2.9, P3.1
/QH: P3.7, SW1.6, SW2.6
/QH/: P3.8, SW1.7, SW2.7
/RCLK: P1.3, P2.8, P3.10
/SH/LD: P1.5, P2.6, P3.4
/SHIFTIN_SER: P3.6, SW1.5, SW2.5
/SHIFTOUT_SER: P3.11, SW1.8, SW2.8
/SHIFT_INH: P1.7, P2.4, P3.5
/SRCLK: P1.1, P2.10, P3.9
/SW1_12: P1.10, SW1.1, SW1.2
/SW1_34: P1.8, SW1.3, SW1.4
/SW2_12: P2.1, SW2.1, SW2.2
/SW2_34: P2.3, SW2.3, SW2.4
GND: P1.9, P2.2, P4.1, P5.1

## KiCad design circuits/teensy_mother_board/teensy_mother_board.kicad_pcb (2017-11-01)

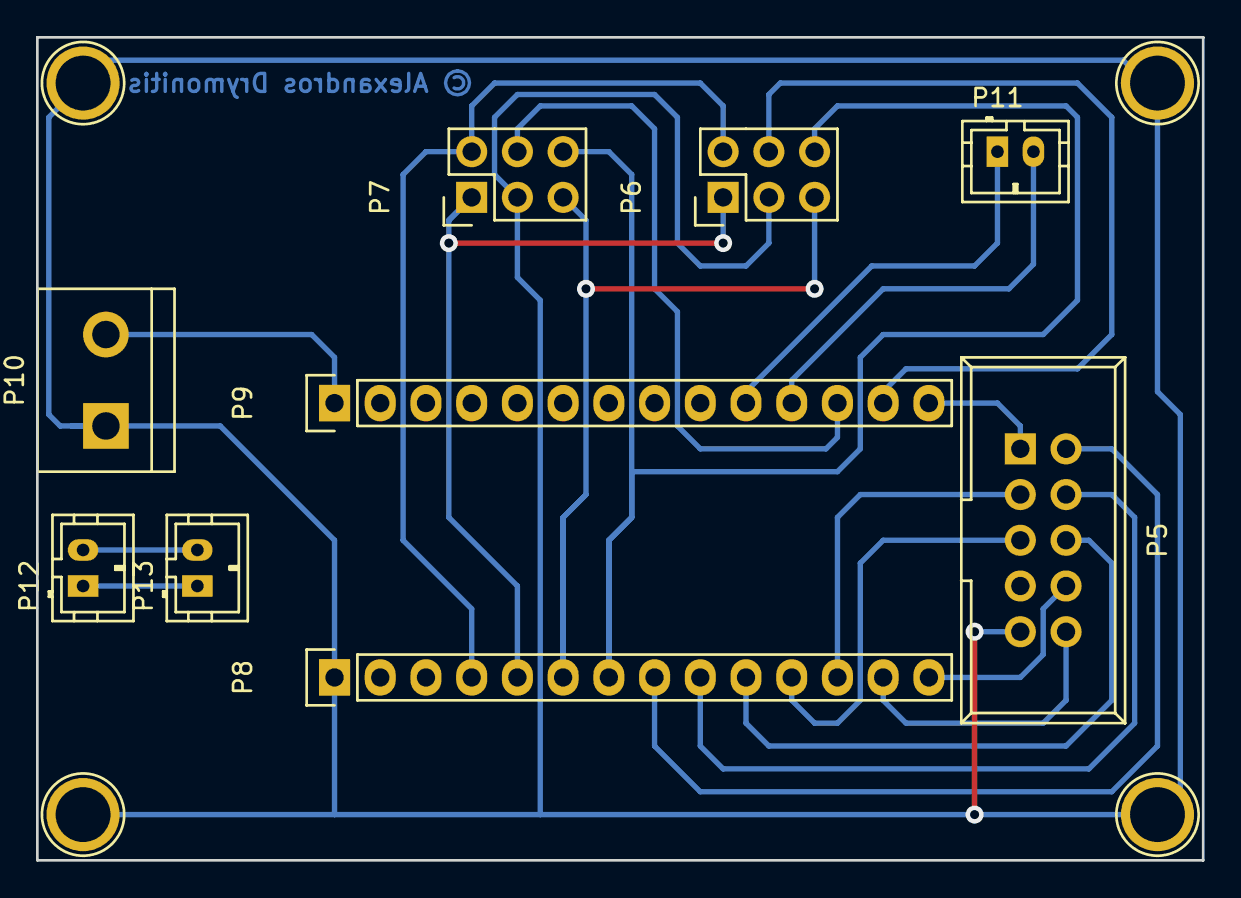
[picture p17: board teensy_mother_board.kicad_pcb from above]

Board: 2 copper layers, 64.8 x 45.7 mm, 13 parts (0 on the bottom side), 20 nets.

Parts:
P1, P2, P3, P4: CONN_01X01; hole
P5: CONN_02X05; IDC_Header_Straight_10pins
P6, P7: CONN_02X03; Pin_Header_Straight_2x03
P8, P9: CONN_01X14; Pin_Header_Straight_1x14
P10: CONN_01X02; bornier2
P11, P12, P13: CONN_01X02; Connectors_JST_B2B-PH-K

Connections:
/ANALOG_IN_A: P6.4, P9.13
/ANALOG_IN_B: P7.4, P9.12
/CONST_HIGH: P9.11, P11.2
/D+: P12.1, P13.1
/D-: P12.2, P13.2
/INPUT_LATCH: P5.5, P8.11
/INTERRUPT: P9.10, P11.1
/MASTER_MUX_A: P6.6, P7.6, P8.7
/MASTER_MUX_B: P6.5, P7.5, P8.6
/MASTER_MUX_C: P6.1, P7.1, P8.5
/MASTER_MUX_D: P6.2, P7.2, P8.4
/MISO: P5.8, P8.14
/MOSI: P5.10, P8.13
/OUTPUT_LATCH: P5.3, P8.12
/SCK: P5.1, P9.14
/SLAVE_MUX_A: P5.6, P8.10
/SLAVE_MUX_B: P5.4, P8.9
/SLAVE_MUX_C: P5.2, P8.8
GND: P1.1, P2.1, P3.1, P4.1, P5.9, P6.3, P7.3, P8.1, P10.1
VCC: P9.1, P10.2

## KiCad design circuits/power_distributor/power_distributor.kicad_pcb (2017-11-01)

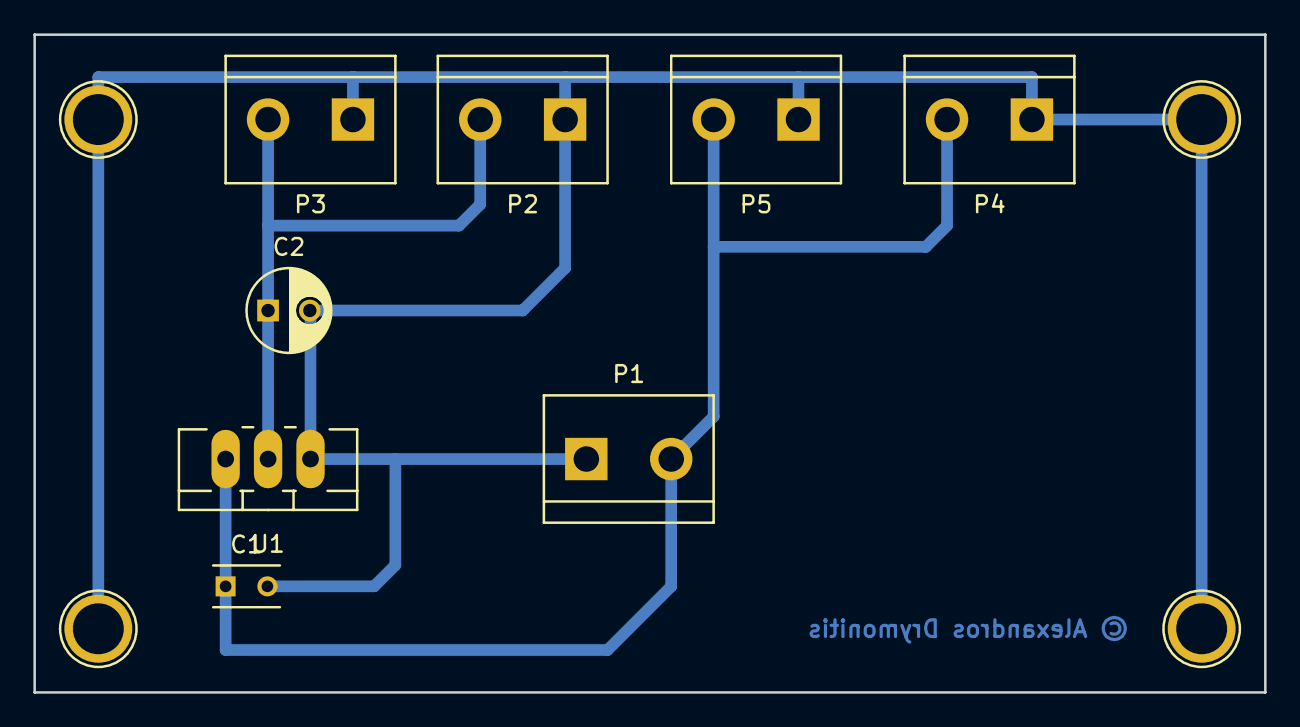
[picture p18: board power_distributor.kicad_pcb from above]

Board: 2 copper layers, 73.7 x 39.4 mm, 12 parts (0 on the bottom side), 3 nets.

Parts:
C1: 100nF; C_Rect_L4_W2.5_P2.5
C2: 10uF; C_Radial_D5_L6_P2.5
P1, P2, P3, P4, P5: CONN_01X02; bornier2
P6, P7, P8, P9: CONN_01X01; hole
U1: LD1117S33TR; TO-220_Neutral123_Vertical_LargePads

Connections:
/VO: C2.1, P2.2, P3.2, U1.2
GND: C1.2, C2.2, P1.1, P2.1, P3.1, P4.1, P5.1, P6.1, P7.1, P8.1, P9.1, U1.1
VCC: C1.1, P1.2, P4.2, P5.2, U1.3

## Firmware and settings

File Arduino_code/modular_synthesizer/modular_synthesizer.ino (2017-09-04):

/*****************************************************************************
 * This Arduino sketch is written for a physical digital modular synthesizer *
 * The control part of this synthesizer runs on a Teensy3.2 (or LC)          *
 * which is programmed in the Arduino language using Teensyduino             *
 * the audio part of the synthesizer runs on aRaspberry Pi 3                 *
 * which is programmed in Pure Data. In order for this code to run, you'll   *
 * need to combine it with the Pd patch that comes with this sketch          *
 *****************************************************************************/

// inculde the SPI library to control the shift registers
#include <SPI.h>

// various MARCO definitions that need to be adjusted according to the synthesizer setup

// define the number of modules you're using
#define NUM_OF_MODULES 6
// define a speed for the SPI library so that it can work properly
// daisy chaining many modules can result in a long distance that needs to be convered
// by the SPI pins. a 8000000 speed worked for me for 12 modules, after that
// I needed to drop it to 4000000. trial and error will probably work here
// if you get funny results, you'll probably need to lower the speed
#define SPISPEED 4000000
// if using a board wih an analog pin resolution greater than 10-bits
// uncomment the line below and set the correct resolution
#define ANALOG_RESOLUTION 13
// clip analog readings for a more unified result
//#define CLIP 8100
// set the filter coefficient for smoothing out the potentiometer readings
// the value should be between 0 and 1. the greater the value, the more the smoothing
// but the less responsive the potentiometers will be, plus the more jitter you'll get the first time you read a pot
// further smoothing is being done in the Pd patch
#define FILTER_COEFF 0.5


/******************************* global variables **********************************/

/******************** variables that change according to setup *********************/


/****************************** output shift registers *****************************/

// array to hold number of signal outputs (banana terminals) of each module
byte outputPins[NUM_OF_MODULES] = { 2, 4, 8, 4, 4, 5 };


/******************************* input shift registers *****************************/

// array to hold binary numbers of signal inputs (banana terminals) of each module
// a 1 is a pin with a banana terminal and a 0 is a pin with no banana terminal
// for example, a module with two signal inputs should get the value B00000011
// signal inputs should be wired from the first input of the shift register and should not skip pins
byte bananaPins[NUM_OF_MODULES] = { B00000011, B00000111, B00001111, B00000111, B00001111, B11111111 };
// array to hold binary numbers of switched of each module
// a 1 is a pin with a switch and a 0 is a pin with no switch
// for example, a module that has three switches (and two signal inputs, like the example above) should get the value B00011100
// switches should be wired after the signal inputs (banana terminals) and should not skip pins
byte switchPins[NUM_OF_MODULES] = { B00001100, B00001000, B00010000, B00000000, B00110000, B00000000 };


/*************************************** multiplexers ******************************/

// master multiplexers (on power buses) controlling the multiplexers of each module
// if your setup has more than 16 modules (which is the number of channels of the CD4067 multiplexer) you'll need more than one
const int numOfMasterMux = 1;
// number of modules (slave multiplexers) sending potentiometer data to each master multiplexer
int numOfSlaveMux[numOfMasterMux] = { 6 };
// 1D or 2D array (according to the number of numOfMasterMux) to hold number of potentiometers on each module
// rows = numOfMasterMux, columns = 16, since the master multiplexers have 16 channels
// even if it's a 1D array, you should still write it as a 2D array, like the example below
int numOfPots[numOfMasterMux][16] = { { 2, 2, 3, 2, 8, 8 } };


/************** end of variables that change according to setup ********************/

/****** no need to further edit the code, unless I've done something wrong... ******/


// variables and MACRO definitions that are constant, regardless of setup

#define BAUDRATE 57600
// the following two interrupt pins are used to detect whether we're shutting down the system
#define CONST_HIGH 16
#define INTERRUPT_PIN 17
// volatile boolean changed by the interrupt signal
volatile bool sendShutDownSignal = false;

// global index for connection, switch and potentiometer functions and loops
// maximum number of bytes to be transfered to Pure Data over serial
// 99% of the times only part of this will be transferred to Pd
// it's size will be calculated in the setup function
int numOfTotalData;
// buffer to hold data transfered to Pure Data over serial
// it's size will be allocated in the setup function because the total_pots variable hasn't been calculated yet
byte *transferData;
// variable to hold analog pin resolution which will be set in the setup() function
// depending on whether the ANALOG_RESOLUTION macro has been declared or not
// defaults to 1023 (10-bit), written analogue here to avoid name collision with Arduino's
// Built-in function analogReadResolution()
int analogueReadResolution = 1023;


/***************************** output shift registers *******************************/

const byte outputLatch = 10;
// byte array to transfer data to output chips via SPI
byte outputData[NUM_OF_MODULES] = { 0 };
// use a variable to hold the sum of the elements of the outputPins array
// it will be calculated in the setup function
int totalNumOutputs = 0;
// boolean to exit the output pins loop when a new connection has been detected
boolean terminateBananas;


/****************************** input shift registers *******************************/

const byte inputLatch = 9;
// array to receive data from input chips via SPI
byte inputData[NUM_OF_MODULES] = { 0 };
// this array will hold the number of total banana terminals on each module which is needed in Pd
// its elements will be calculated in the setup function
byte totalInputBananas[NUM_OF_MODULES];
// this byte will hold the total number of inputs in the whole system and will be sent to Pd so that the matrix can be created
byte totalNumInputs;
// this array will hold the number of total switches on each module which is needed in Pd
// its elements will be calculated in the setup function
byte totalNumSwitches[NUM_OF_MODULES];
// variable to store the pin of the first switch of each module
// its elements will be calculated in the setup function
byte firstSwitch[NUM_OF_MODULES] = { 0 };
// two-dimensional array to hold the states of banana plugs
// rows = totalNumOutpus, columns = NUM_OF_MODULES
// it's size will be allocated in the setup function because the totalNumOutputs variable hasn't been calculated yet
byte **bananaStates;
// array to store states of switches
byte switchStates[NUM_OF_MODULES];


/********************************** multiplexers ************************************/

// number of control pins the master multiplexers have (no accumulation for more than one mux used)
// for a 16-channel mux it's 4 (2^4 = 16)
const int numMasterCtlPins = 4;
// the next two arrays will have their elements calculated in the setup function
// and they will be used in the readPots() function to set the control pins of the master multiplexers
int masterCtlPins[numMasterCtlPins];
int masterCtlValues[numMasterCtlPins];
// number of control pins the slave multiplexers have (no accumulation for more than one mux used)
// for an 8-channel mux it's 3 (2^3 = 8)
const int numSlaveCtlPins = 3;
// the next two arrays will have their elements calculated in the setup function
// and they will be used in the readPots() function to set the control pins of the slave multiplexers
int slaveCtlPins[numSlaveCtlPins];
int slaveCtlValues[numSlaveCtlPins];
// variable to hold the total number of potentiometers which will be calculated in the setup function
int totalPots = 0;
// pointer to create an array with values that will be used for smoothing
// its size is calculated in the setup() function and it contains one element per potentiometer
float *smoothedVals;
// array to store and back up activity of modules
// the potentiometers of each module will be either read or not read according to their activity
// Pd sends the activity values
byte activeModules[NUM_OF_MODULES] = { 0 };
// lastly a boolean to set whether a CLIP macro has been defined or not, which is used in the readPots() function
boolean clip = false;
// and an int which defaults to the set analog resolution, unless it's defined at the top of the code
int clipVal;


/********************************* Custom functions **********************************/

// function to transfer data to the output shift registers via SPI
void refreshOutput() {
  digitalWrite(outputLatch, LOW);
  for(int i = NUM_OF_MODULES - 1; i >= 0; i--){
    // send a byte to the next register
    SPI.transfer(outputData[i]);
  }
  digitalWrite(outputLatch, HIGH);
}

// function to receive data from the input shift registers via SPI
void refreshInput() {
  digitalWrite(inputLatch, LOW);
  digitalWrite(inputLatch, HIGH);
  for(int i = 0; i < NUM_OF_MODULES; i++){
    // send a value of 0 to read the first byte returned
    inputData[i] = SPI.transfer(0);
  }
}

void checkConnections(int pin, int module) {
  int localIndex = 1;

  // store the first altered state of input bytes to the transfer array
  for(int i = 0; i < NUM_OF_MODULES; i++){
    // mask the input byte to exclude any possible switches on the module and check if changed
    byte maskedBanana = inputData[i] & bananaPins[i];
    // check if the input byte has changed and only then send the corresponding data to Pd
    if(maskedBanana != bananaStates[pin][i]){
      // store generic data index (0) and number of expected bytes beyond that which are
      // secondary index for generic data (check Pd patch), 1 is for connection data
      // input chip byte (split in two)
      // number of input pins of current chip
      // number of output pin
      // and total number of input pins
      transferData[localIndex++] = 0;
      transferData[localIndex++] = 6;
      transferData[localIndex++] = 1;
      transferData[localIndex++] = maskedBanana & 0x7f;
      transferData[localIndex++] = maskedBanana >> 7;
      transferData[localIndex++] = totalInputBananas[i];
      // matrixes from iemmatrix in Pd start counting from 1
      transferData[localIndex++] = pin + 1;
      // we first zero the total number of input chips
      transferData[localIndex] = 0;
      // and then we check if we're not in the first module
      if(i){
        // if we're not in the first module, we accumulate the number of previous modules' input pins
        // and increment localIndex
        for(int j = 0; j < i; j++) transferData[localIndex] += totalInputBananas[j];
        localIndex++;
      }
      else{
        // otherwise we just increment localIndex
        localIndex++;
      }
      //updateModules(maskedBanana, pin, module, i);
      // update the bananaStates array
      bananaStates[pin][i] = maskedBanana;
      // set the loop termination boolean to true, update the global index and exit loop
      terminateBananas = true;
      break;
    }
  }
  if(localIndex > 1) Serial.write(transferData, localIndex);
}

void checkSwitches() {
  int localIndex = 1;

  for(int i = 0; i < NUM_OF_MODULES; i++){
    // mask the input byte according to the position of the switches and check if changed
    byte maskedSwitch = inputData[i] & switchPins[i];
    if(maskedSwitch != switchStates[i]){
      // if changed, store a 1 which denotes module data instead of generic data
      // the extra index 1 to denote that the following values are switch values
      // the module index (starting from 0)
      transferData[localIndex++] = 1;
      transferData[localIndex++] = 1;
      transferData[localIndex++] = i;

      // afterward store the data for splitting the byte with the switch values
      // this is number of switches of current module
      // pin number of the first switch of the current module
      // and input chip byte split in two
      transferData[localIndex++] = totalNumSwitches[i];
      transferData[localIndex++] = firstSwitch[i];
      transferData[localIndex++] = maskedSwitch & 0x7f;
      transferData[localIndex++] = maskedSwitch >> 7;
      
      // update the switchStates array and the global index and exit loop
      switchStates[i] = maskedSwitch;
      break;
    }
  }
  if(localIndex > 1) Serial.write(transferData, localIndex);
}

// function to read potentiometers of active modules
void readPots() {
  // set local index to global index's current value
  int localIndex = 1;
  // set row index for 2D array multiple pots (potIndex)
  int potIndex = 0;
  int moduleIndex = 0;
  //static byte smoothIndex = 0;
  // run througn all master multiplexers
  for(int masterMux = 0; masterMux < numOfMasterMux; masterMux++){
    // run through all slave multiplexers
    for(int slaveMux = 0; slaveMux < numOfSlaveMux[masterMux]; slaveMux++){
      // if this module is active, store a 1 which denotes module data instead of generic data
      // the extra index 0 to denote that the following values are potentiometer values
      // the module index (starting from 0)
      // and the number of potentiometers
      // Note: activity of modules is being stored in the checkConnections function
      if(activeModules[moduleIndex]){
        transferData[localIndex++] = 1;
        transferData[localIndex++] = 0;
        transferData[localIndex++] = moduleIndex;
        transferData[localIndex++] = numOfPots[masterMux][slaveMux];

        // set the control pins of the current master multiplexer
        for(int i = 0; i < numMasterCtlPins; i++)
          digitalWrite(masterCtlPins[i], (slaveMux & masterCtlValues[i]) >> i);
      }
      // run through the pins used on each slave multiplexer
      // the active module test needs to be separate here in order to be able
      // to increment the potIndex variable at every iteration of the loop below
      for(int pot = 0; pot < numOfPots[masterMux][slaveMux]; pot++){
        // if this module is active store the values of its potentiometers
        if(activeModules[moduleIndex]){
          // set the control pins of the current slave multiplexer
          for(int i = 0; i < numSlaveCtlPins; i++)
            digitalWrite(slaveCtlPins[i], (pot & slaveCtlValues[i]) >> i);
          // add a short delay to establish a better reading of the analog input
          delayMicroseconds(10);
          // read the corresponding analog pin of the Teensy
          int potVal = analogRead(masterMux);
          // smooth out the analog reading
          int smoothed = smooth(potVal, potIndex);
          // clip the values for a more unified result if a CLIP macro has been defined
          // clip to CLIP - 1 for correct table reading in Pd
          if(clip) if(smoothed > clipVal) smoothed = clipVal;

          // and store the smoothed value split in two to the transferData array
          transferData[localIndex++] = smoothed & 0x007f;
          transferData[localIndex++] = smoothed >> 7;
        }
        potIndex++; // update the 2D array row index anyway
      }
      // the module index is independent of activity as well, it should always increment
      moduleIndex++;
    }
  }
  if(localIndex > 1) Serial.write(transferData, localIndex);
}

int smooth(int valToSmooth, int index) {
  smoothedVals[index] = (valToSmooth * (1 - FILTER_COEFF)) + (smoothedVals[index]  *  FILTER_COEFF);

  return (int)smoothedVals[index];
}

void resetConnections() {
  for(int i = 0; i < totalNumOutputs; i++){
    for(int j = 0; j < NUM_OF_MODULES; j++){
      bananaStates[i][j] = 0;
      activeModules[j] = 0;
    }
  }
}

void resetSwitches() {
  for(int i = 0; i < NUM_OF_MODULES; i++)
    switchStates[i] = 0;
}

void sendNumInputsOutputs() {
  int localIndex = 1;

  // store generic data index
  transferData[localIndex++] = 0;

  // tell Pd how many more bytes to expect beyond the first index
  // one for the extra data index, one for the number of inputs and one for the number of outputs
  transferData[localIndex++] = 3;

  // secondary index 2 indicates number of inputs and outputs data
  transferData[localIndex++] = 2;

  transferData[localIndex++] = totalNumInputs;
  transferData[localIndex++] = totalNumOutputs;

  Serial.write(transferData, localIndex);
}

void sendAnalogReadResolution() {
  int localIndex = 1;

  // store generic data index
  transferData[localIndex++] = 0;

  // after this, we should expect the generic data secondary index and the analogRead resolution split in two
  transferData[localIndex++] = 3;

  // as a secondary index a 0 denotes the analog resolution data
  transferData[localIndex++] = 0;
  transferData[localIndex++] = analogueReadResolution & 0x7f;
  transferData[localIndex++] = analogueReadResolution >> 7;

  Serial.write(transferData, localIndex);
}

// interrupt and shut-down functions

void shutDown() {
  sendShutDownSignal = true;
}

void sendShutDown() {
  int localIndex = 1;

  // store the generic data index
  transferData[localIndex++] = 0;

  // let Pd know how many more bytes to expect; one byte is the extra index which will result in a bang after [route]
  transferData[localIndex++] = 1;

  // secondary index denotes shut down data
  transferData[localIndex++] = 3;
  sendShutDownSignal = false;

  Serial.write(transferData, localIndex);
}

void readSerialData() {
  static int serialVal, whichModule, whichPin, pinVal;
  static bool inputStarted, endNotificationSent;
  byte inByte;
  
  if(Serial.available()){
    inByte = Serial.read();

    // check if we've received the start character and notify Pd of Teensy's serial buffer availablility
    if (inByte == '<') {
      inputStarted = true;
      endNotificationSent = false;
      int localIndex = 1;
      // store generic data index
      transferData[localIndex++] = 0;
      // after this, we should expect the generic data secondary index and the serial buffer availability
      transferData[localIndex++] = 2;
      // as a secondary index a 4 denotes the serial buffer state
      transferData[localIndex++] = 4;
      transferData[localIndex++] = 0;
      Serial.write(transferData, localIndex);
    }
    // once we received the start character we can process the rest of the incoming bytes
    if (inputStarted) {
      if(isDigit(inByte))
        serialVal = serialVal * 10 + inByte - '0';
      else{
        if(inByte == 'm'){
          whichModule = serialVal;
          serialVal = 0;
        }
        else if(inByte == 'p'){
          whichPin = serialVal;
          serialVal = 0;
        }
        else if(inByte == 'v'){
          pinVal = serialVal;
          bitWrite(outputData[whichModule], whichPin, pinVal);
          serialVal = 0;
        }
        else if(inByte == 'a'){
          activeModules[whichModule] = serialVal;
          serialVal = 0;
        }
        else if(inByte == 'i'){
          sendNumInputsOutputs();
        }
        else if(inByte == 'b'){
          sendAnalogReadResolution();
        }
        else if(inByte == 'r'){
          resetConnections();
          resetSwitches();
        }
        // when we receive the end character we can notify Pd of the serial buffer availability again
        else if (inByte == '>') {
          inputStarted = false;
          if (!endNotificationSent) {
            int localIndex = 1;
            // store generic data index
            transferData[localIndex++] = 0;
            // after this, we should expect the generic data secondary index and the serial buffer availability
            transferData[localIndex++] = 2;
            // as a secondary index a 4 denotes the serial buffer state
            transferData[localIndex++] = 4;
            transferData[localIndex++] = 1;
            Serial.write(transferData, localIndex);
            endNotificationSent = true;
          }
        }
      }
    }
  }
}


/******************************** Built-in functions ********************************/
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
void loop() {
  // control LEDs from Pd
  readSerialData();

  // write to output shift registers and read input shift registers
  // first set terminate boolean to false
  terminateBananas = false;
  // pin number variable
  int pin = 0;
  for(int i = 0; i < NUM_OF_MODULES; i++){
    // add number of pins of previous chip
    if(i) pin += outputPins[i - 1];
    // then go through the banaba plug pins
    for(int j = 0; j < outputPins[i]; j++){
      int localPin = pin;
      // set the current pin HIGH
      bitSet(outputData[i], j);
      refreshOutput();
      // give some time to the shift registers to do their job
      delayMicroseconds(1);
      refreshInput();
      // give some time to the shift registers to do their job
      delayMicroseconds(1);
      // add current and previous pins of current chip
      localPin += j;
      checkConnections(localPin, i);
      // reset the pin LOW
      bitClear(outputData[i], j);
      // check if a new connection has been detected and if so, exit loop
      if(terminateBananas) break;
    }
    if(terminateBananas) break;
  }

  checkSwitches();

  readPots();

  if(sendShutDownSignal){
    // if the interrupt pin received a signal change
    sendShutDown();
  }
}

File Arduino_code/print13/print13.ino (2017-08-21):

// This sketch tests whether it's possible to write the value 13 from the Teesny to the Arduino
// using the Serial.print() function, in case Serial.write(13) doesn't work.
// It is possible that instead of 13, Pd receives a 10.
// Upload this sketch to the Teensy and open the test13.pd patch.
// If you get a 13 printed into Pd's console, you're good to go.
// Upload the modular_synthesizer_print.ino sketch to the Teensy and open the modular_synthesizer.pd patch
// If instead of 13 you get a 10, upload the modular_synthesizer13.ino sketch
// and in the modular_synthesizer.pd patch, change the [arduino_data] and [matrix_connections] abstractions
// with the [arduino_data13] and the [matrix_connections13] abstractions. The rest should work as expected

void setup() {
  Serial.begin(57600);
}

void loop() {
  Serial.print((char)13);
  delay(500);
}

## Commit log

2016-08-11 added circuit schematics and desings
    [module_generic_bottom_board.brd, module_generic_bottom_board.sch, module_generic_top_board.brd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]
2016-11-18 Update [arduino_data] abstraction
2016-11-18 Fixed smoothing issue in Arduino code
    [modular_synthesizer.ino]
2017-07-01 Update Arduino sketches
2017-07-17 Include schematic .pdf files
2017-07-17 Update Arduino code
2017-08-16 Update module specific board
    [module_specific_board.kicad_pcb, module_specific_board.sch, parts_list.csv]
2017-09-03 Update 13-bug fix abstractions
    [modular_synthesizer13.ino, modular_synthesizer_print.ino]
2017-09-03 Update 13-bug fix code
    [modular_synthesizer13.ino, modular_synthesizer_print.ino.ino]
2017-09-03 Update [arduino_data13]
2017-09-04 Update gerber files
    [module_specific_board-B.Cu.gbr, module_specific_board-B.Mask.gbr, module_specific_board-B.SilkS.gbr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]
2017-09-04 Update module_generic_bottom_board
    [module_generic_bottom_board-B.Cu.gbr, module_generic_bottom_board-B.Mask.gbr, module_generic_bottom_board-B.SilkS.gbr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]
2017-09-07 Update parts list
    [parts_list.csv]
2017-10-24 Update circuits
    [module_generic_bottom_board-B.Cu.gbr, module_generic_bottom_board-B.Mask.gbr, module_generic_bottom_board-B.SilkS.gbr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]
2017-10-24 Added Module Specific Board 2
    [module_specific_board.sch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]
2017-10-24 Update Module Generic Top Board
    [module_generic_top_board-B.Cu.gbr, module_generic_top_board-B.Mask.gbr, module_generic_top_board-B.SilkS.gbr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]

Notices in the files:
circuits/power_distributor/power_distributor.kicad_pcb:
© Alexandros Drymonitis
